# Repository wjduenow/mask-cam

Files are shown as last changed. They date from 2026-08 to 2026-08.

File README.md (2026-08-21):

# mask-cam — a Gini Raksha mask that carries an ESP32-S3-CAM

Converts **Sri_Lankan_Mask_2.3mf** (Tbridge3D, *Sri Lankan Mask (Gini Raksha)*) into a
housing for a nulllab / emakefun **ESP32-S3-CAM**, with the lens looking out of the brow,
a 55 × 55 × 12 mm cell inside, and the electronics sealed behind a screwed cover. It
hangs on a wall or drops onto a printed stand, using the same two mounting points.

| | |
|---|---|
| **Overall** | **193.2 × 74.4 × 187.9 mm** — the donor at **1.75×**, silhouette untouched |
| **Mask** | 323.7 cm³, **~401 g** PLA, watertight, one body |
| **Aperture** | **Ø7.6 at (x 0, z 91)** — the brow, on the mirror line. **79–165°** unvignetted |
| **Battery** | **55 × 55 × 12 mm** cell in a 58 × 58 pocket, 21.2 mm of interior |
| **Parts** | `mask_cam` · `cover` · `stand` · `camera_clamp` · `battery_shim` · `camera_shims` · `eye_plugs` |
| **Power** | [DWEII Type-C boost + charge module](https://www.amazon.com/dp/B09YD5C9QC), 25 × 20 mm — cradled in the board bay, plug enters from below |
| **Nothing protrudes** | past the wall plane except the cover's own hanging pads |

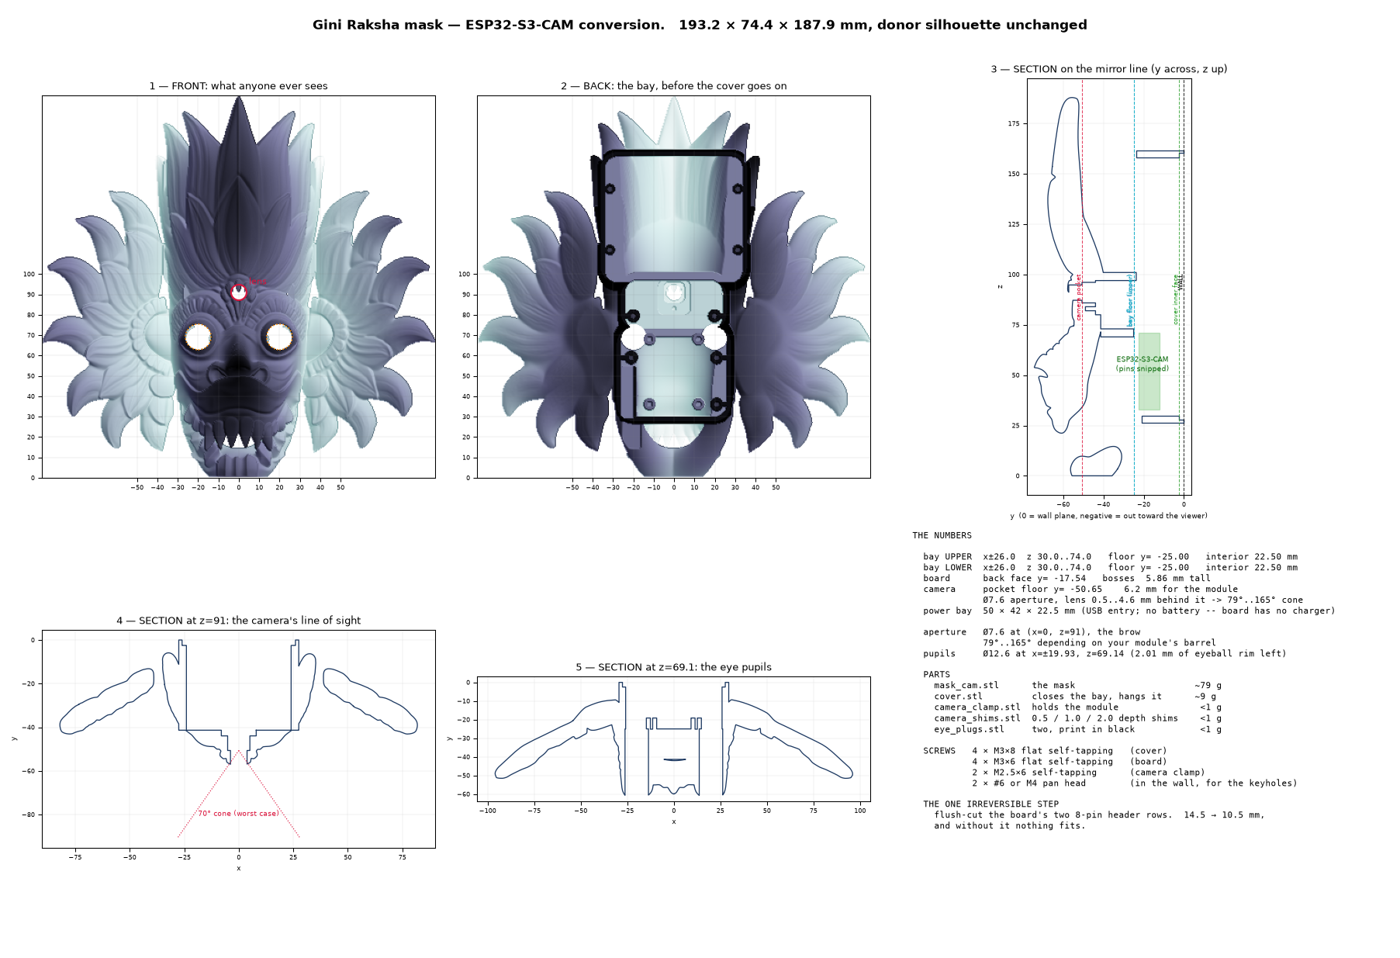
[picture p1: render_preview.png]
preview


---

## 0. You need the donor model — it is not in this repository

Everything here is a **conversion of a third-party model**, and none of it builds without
that model:

> **Sri Lankan Mask (Gini Raksha)** — designer **Tbridge3D** — *Standard Digital File
> License*

That licence covers printing it yourself; it does **not** cover redistribution, so the
file is deliberately absent, along with `mask_cam.3mf` (which carries its geometry
unchanged) and the designer's own product photographs.

Get your own copy, save it beside these scripts as **`Sri_Lankan_Mask_2.3mf`**, then:

```bash
python build_all.py --force      # re-samples the donor and regenerates everything
```

Every derived file — the sampled grids, the mask, the cover, the stand and all the small
parts — is reproduced from it. What lives here is the conversion: the parameters, the
solid modelling, the measurement scripts, and the checkers that refuse to let it lie.

---

## 0.5 Where this stands

Everything in this repository builds and passes its checkers. What is **printed** and what
is **current** are not the same thing:

| | state |
|---|---|
| `mask_cam.stl` | built + verified — **not yet printed** in this form |
| `cover.stl` | built + verified — **not yet printed** in this form |
| `power_clamp.stl` | new — not yet printed |
| `camera_clamp.stl` | **printed, fits** |
| `battery_shim.stl`, `camera_shims.stl`, `eye_plugs.stl` | built + verified |

An earlier mask and cover were printed and are superseded — they predate the cover posts,
the board bosses, the SD-card clearance and the DWEII pocket.

**Power is wired** as far as the cell → module pair; the module's `5V ±` to the cam board
was the step in progress. The boost auto-starts, so nothing needs to come out through the
cover.

Two numbers are still soft, both flagged where they are used: the SD card's span along the
cam board (photo-scaled, `SD_MARGIN` carries 1.0 mm against it) and the DWEII module's
thickness (not dimensioned on its drawing; the pocket is cut oversize so it cannot bite).

One decision is open: the **USB-C port arrangement**. Today the plug enters from under the
chin and needs a slim cable. A cable feed-through with the module somewhere roomier was
raised and never settled.

---

### Resuming with Claude

`CLAUDE.md` holds the operational notes — how to run things, how long each step takes, the
measurement traps that cost time here, and the two rules the project runs on. It loads
automatically. `.claude/skills/parametric-3d-printing/` is bundled so CadQuery work has its
reference to hand.

---

## 1. The idea: carve the bay out of the relief, don't add a box to the back

The donor looks like a thin shell and is not. Ray-sampling it shows **8–27 mm of solid
plastic** (at 1×) over a hollow back, and the relief you actually see is only the outer
few millimetres. So the electronics bay is **milled into that thickness from behind**, and
the apertures are bored through what is left. That is why the silhouette is untouched and
the mask still hangs flat.

### Why 1.75×

The hardware does not scale. That asymmetry is the whole point: at 1× the board, the
camera and a battery were fighting over one short column; at 1.75× each gets its own place.

| | usable column | needed | verdict |
|---|---|---|---|
| 1.0× | 67 mm | 117 mm | ✗ no battery; camera trapped under the board |
| 1.5× | 118 mm | 117 mm | +1 mm — nowhere for cover screws, no home for the charger |
| **1.75×** | **154 mm** | 117 mm | **+37 mm** ✓ |
| 2.0× | 176 mm | 117 mm | +59 mm, but **621 g** |

The column is bounded below by the teeth and above by the crown, which is one continuous
piece only up to **z ≈ 164** — past that it is five separate petals (§5). 2× buys margin
you don't need for another 200 g of filament.

---

## 2. Layout

Three zones, each sized from the measured surface by `analyze_layout15.py`:

| zone | x | z | interior | holds |
|---|---|---|---|---|
| **BOARD** | ±26 | 30 – 74 | **22.50 mm** | the ESP32-S3-CAM (z 32–72) |
| **CAM** | ±24 | 73 – 97 | **35.91 mm** | camera at z 91, DWEII module (25 × 20) behind its clamp |
| **BATT** | ±34 | 96 – 158 | **21.20 mm** | the 55 × 55 × 12 cell |

**The camera is clear of the board** — z 91 against a board ending at z 72. At every
smaller scale the central column was too short and the camera had to live *underneath* the
board, meaning four screws out before you could touch it. It is now serviceable alone.

**The cell has real fixings.** At 1.5× the 58 mm pocket filled its zone edge-to-edge and
the cover's battery section was a 58 mm cantilever held by foam pressure. At 1.75× the
zone is 68 wide against a 58 pocket, so four **Ø5** posts flank the cell — ten cover screws
in total.

---

## 3. Why the brow and not the eyes

You asked for the eyes first, and the eyes are the better-looking site. They are also, by a
factor of five, the **worst optical site on the mask**, and that is measured.

The lens can only get as close to its aperture as the surrounding relief lets the module's
pocket reach. `analyze_fov.py` measured that at every candidate (1× figures):

| site | lens setback | cone at Ø7.2 |
|---|---|---|
| right eye | **11.5 mm** | **35°** |
| left eye | 12.0 mm | 33° |
| mouth | 16.0 mm | 25° |
| nostril | 1.6 mm | 133° |
| **brow** ← | **1.0–5.3 mm** | **71–151°** |

The eyeball is a solid hemisphere boss with thick relief all round it; the brow is a thin
skin over the deep central cavity. A central bore on a Raksha mask reads as an **urna /
third eye** — an authentic motif rather than damage.

### What the lens actually gets

⚠️ **Correcting an earlier claim.** This section used to say the setback was "set to
3.0 mm, giving a 103° cone". `LENS_SETBACK = 3.0` was a stated intent that the geometry
never implemented — the pocket floor is derived from the *relief limit*, not from that
parameter, so the number was dead and the 103° was wrong.

With the module now measured at **6.20 mm** front-of-lens to back (2026-08-18), here is
what it really gets:

| module sits | setback | unvignetted cone |
|---|---|---|
| face flat on the pocket floor, nothing in the bore | 4.59 mm | **79°** |
| barrel nosed the full 4.6 mm up the Ø7.6 bore | 0.50 mm | **165°** |

The geometry assumes the **pessimistic** end: the pocket floor sits at the relief limit
(53.15 mm proud, cut to 50.65, leaving exactly the 2.50 mm wall), and nothing is assumed
to enter the bore. Any real barrel protrusion only moves the lens closer to the aperture,
which widens the view — it can never make it worse.

**79° is the number that matters, and it is comfortably enough.** A stock OV2640 lens is
65–70°, so even at the pessimistic end the aperture never crops the sensor's image. The
glass also sits 4.6 mm down a dark tunnel, so no lens is visible from the front.

> ⚠️ **The sensor is an OV3660, not an OV2640.** Firmware bring-up read the PID off the
> part on 2026-08-20: `0x3660`. The paragraph above was written against the OV2640's
> figures. OV3660 modules ship with comparable glass, so the conclusion very probably
> survives — but the 65–70° it leans on is now an assumption about a part we have not
> measured, and only a photograph through the finished aperture will settle it. The
> aperture is oversized against 79° anyway, which is the margin that makes this a footnote
> rather than a problem. See `firmware/README.md`.

Both eyeballs get **Ø12.6** bores and printed blanking plugs — the symmetry is what makes
the brow bore read as ornament. The aperture itself is **not** scaled: it only has to pass
the real Ø7.0 lens, so on the bigger mask it is proportionally smaller and harder to spot.

---

## 4. Where every number came from

The honest ledger. ⚠ rows are the ones that move plastic.

### Measured off the donor mesh (0.5 mm ray grid, re-run on every build)

| what | value | how |
|---|---|---|
| bounding box | 193.2 × 74.4 × 187.9 | trimesh, watertight |
| **eyeball centres** | **x = ±19.9, z = 69.1** | peak stand-off in the eye band, centroid-fitted |
| crown continuity | one piece to **z ≈ 164** | connected-component scan per z row |
| BOARD zone | 39.60 mm worst stand-off | rectangle minimum over x±26, z 30–74 |
| CAM zone | 41.41 mm | over x±24, z 73–97 |
| BATT zone | 26.70 mm | over x±34, z 96–158 |

> **The eyeball detection is self-checking.** The two caps come out symmetric to **0.14 mm
> in x and 0.00 mm in z**. A detector locking onto noise does not do that — an earlier
> version whose search band was left in *unscaled* coordinates landed on the **nostrils**
> and returned 3.5 mm caps instead of 7 mm. If you change `MASK_SCALE`, check that
> agreement before trusting the result.

### From the vendor's KiCad STEP (via `../sonos-nest/hardware/cam-button`)

| what | value |
|---|---|
| PCB | 30.4 × 38.4 × 1.60 (40.0 overall with the USB-C shell) |
| mounting holes | Ø3.20 on 24 × 32, Ø6.40 keep-out — **M3, not M2**. ✅ Confirmed by a 40.00 mm measured diagonal |
| tallest top-side part | 4.96 (USB-C shell) from the PCB **back** face |

### Measured on the board in hand (V1.1, 2026-08-18)

| what | value | consequence |
|---|---|---|
| header rows | **bare plated holes** | nothing to snip — the old "flush-cut the pins" step is void |
| J1 / J2 | **unpopulated footprints** | the back face is flat |
| total thickness | **7.50 mm** with power wires on | `REAR_PROTRUSION` = 2.54 |
| **camera module** | **6.20 mm** lens front → back | supersedes the 5.0 + 2.0 estimate; pocket offers 6.70 |
| VBAT with USB connected | **0 V** | **there is no charger on this board** (§7) |

### Derived, never typed

```
FLOOR_Y_*    = -(min stand-off over the zone - FRONT_WALL)
BOARD_SEAT_Y = FLOOR_Y_UP + BOARD_FRONT_CLR + COMP_Z_MAX - PCB_T
CAM_SEAT_Y   = CAM_POCKET_Y + CAM_MODULE_DEPTH + 0.5
```

Change `MASK_SCALE`, `FRONT_WALL` or a zone outline and everything downstream moves with
it. There is no second number to forget.

---

## 5. The checks, and what they caught

`build_mask.py` runs **55 clearance checks before it will build**; `verify.py` re-measures
the **exported STL** afterwards with **16 more**. Between them they caught six real
defects:

- **The bay floors.** A hand-made sampling table said they were fine; the true rectangle
  minima would have broken through the relief by 0.68 mm.
- **Every boss and post was floating.** The bay floor is a *plane* at the zone's worst
  case; the donor's back is a *dish*, already deeper than that plane almost everywhere, so
  pillars based on it stood in 2.5–7.6 mm of nothing. Each is now rooted on its own local
  rear surface.
- **Board bosses were 1.6 mm too tall** — they topped out at the PCB's *back* face when the
  board seats on its *front*, inside the Ø6.4 keep-out ring. Exactly `PCB_T` of error.
- **The battery zone severed the crown.** Reaching past z ≈ 164 put its top wall across
  five separate petals, and because the wall sits behind their rear surfaces it never
  merged — the mesh came apart into four bodies. Petals are not structural ground.
- **The USB-C port cut sat at floor depth** instead of on the receptacle's midline, eating
  forward into the muzzle and leaving 1.28 mm of relief.
- **The module was captured, not fastened.** Its pocket had a lid across the mouth and
  the cover closed the far end, so there was no way to screw it down and the soldered
  wires had to be dressed while feeding a board into a blind slot. The pocket is open to
  the bay now, with an **undercut lip** at the bottom — which is why the cradle is built
  as its own boolean assembly in `build_pillars()` rather than as one cutter: a lip that
  overhangs the mouth *without* making the pocket shallower cannot be cut in one pass.
- **The cam board is 38 mm wide, not 30.4.** With a microSD card seated, the slot region
  juts **7.6 mm past one long edge**, and nothing in `mask_params.py` knew — the whole bay
  was laid out around a bare PCB. Measured off the board's own 32 × 24 mm hole pattern in
  an assembly photo, the card occupies **z 51.7–66.0** and reaches **x = −22.80**, which
  put it straight through the DWEII cradle (4.3 mm of overlap) and through the cover post
  at (−21, 59). The card cannot move — it is where the board's slot puts it — so the
  cradle moved to the **+x** wall and the board-zone posts were re-cut around both. ⚠ The
  z band is photo-scaled; `SD_MARGIN` carries 1.0 mm against it.
- **A mount was cut for a part that is not in this build.** `mask_params.py` carried a
  `UC_*` block for a SparkFun-pattern USB-C breakout — 21.4 × 14.5 × 4.75, two M3 holes
  16.85 apart — copied from `../sonos-nest/hardware/jukebox-7`. README §7 had *already*
  replaced that part with the DWEII module, and the part in hand was always the DWEII
  ([B09YD5C9QC](https://www.amazon.com/dp/B09YD5C9QC), drawing in `dweii_spec.jpg`). A
  pad, two pilots and a port channel were cut for a board nobody owns, and the board-zone
  post layout was re-cut around it. Its numbers could not have worked either: the slab
  outboard of that pad is **4.87 mm**, not the nominal wall, so its 6 mm pilots came out
  through the cheek. The whole block is gone; the mount now derives from `PWR_*`, and the
  module is cradled rather than screwed because it **has no mounting holes**.
- **Every cover post and every board boss was built, then deleted.** `build_mask.py`
  unioned the pillars into the mask and *then* carved the bay, and the zone cutters span
  each zone's whole footprint from its floor back to the wall plane — so all 14 pillars
  were erased by the bay they stood in. The exported mask had cover screw holes with
  nothing behind them and a board with nothing to sit on, for months, and `verify.py`
  reported "all checks passed" because it never looked. Walls are added before the carve
  now and pillars after it; §4b of `verify.py` probes the mesh for all 14 and their
  pilots.
- **Two collisions the deleted posts had been hiding.** With the pillars restored, the
  posts at (±21, 68) turned out to sit **1.56 mm** off the eye-pupil axis — inside a
  Ø12.6 bore that needs 9.55 mm of clearance — and capped both pupils; and the post at
  (−21, 36) went straight through the USB-C breakout, leaving gaps of 1.75 and 2.55 mm
  for a board 4.75 mm thick. The board-zone layout was re-cut around all three claimants
  (pupils, breakout, cam board), and `check_clearances()` now asserts each one.
- **The USB-C breakout mount was specified but never built.** `mask_params.py` had the
  pad, the pilots, the port and the receptacle offsets; `build_mask.py` referenced none
  of them. It also could not have worked as written: the slab outboard of the pad is
  **4.87 mm**, not the nominal wall, so the 6 mm pilots would have come out through the
  cheek — the mask's silhouette runs out before its wall does.
- **Three measurement bugs found while fixing those.** A pupil diameter measured by
  line-of-sight through the whole mask reported 11.0 mm for a 12.6 bore, because a boss
  legitimately stands behind it — it now measures the bore itself. A relief sample cast
  exactly along the USB-C pad's face grazed it, returned an odd number of crossings, and
  reported 0.00 mm of relief where there is 19; the sample grid is nudged off round
  numbers now. And a cutter left flush with that same face made a coplanar pair in the
  boolean.
- **The camera clamp was cut to a seat that does not exist.** `CAM_SEAT_Z1` asks for
  z = 102, but the battery zone's floor crosses the waist at z = 97 and sits 20 mm
  *behind* the seat, so the last 5 mm of it is a sealed void inside solid plastic — and
  the second clamp pilot went into that void. The clamp came out 21.5 mm long for a
  17.0 mm recess and had one of its two screw holes over nothing. Every dimensional check
  passed: they all asked the *parameters* whether the seat was 22 mm long, and none asked
  the *mesh*. `verify_smalls.py` now places both small parts in the mask mesh and fails on
  any overlap, and `build_mask.py` asserts that no seat outruns its own zone and no pilot
  lands where a screwdriver cannot reach.
- **The keyholes were inverted** — entry circle above, capturing slot below. Every
  dimensional check passed, because none of them asked which way up it was; the mask would
  simply have slid off the screws. `verify_cover.py` now asserts the entry sits *below* the
  resting position, and probes the mesh for solid material above the shank.
- **Extending the bay downward filled a tooth gap.** A wider lower bay put its wall through
  the mask's teeth; `verify.py` caught it closing one. Face area in the muzzle is paid for
  out of the mouth.

It also caught **three bugs in itself**, worth recording because a checker that measures
the wrong thing is worse than none:

- `cast()` returns crossings **rear-first**, but the relief check took `ys[0] - ys[1]` —
  the *rearmost* solid span. At the failing point the spans were 1.28 / 14.32 / **8.12**
  and the relief was the 8.12. It now sums solid material **forward of the bay floor**,
  ignoring sub-0.15 mm tessellation slivers (reported, not hidden).
- Volume bounds, sample points and the eye search band were all hardcoded at 1×.
- A 1e-6 mm tolerance flagged manifold's own floating-point noise as a geometry change.

Current result on the exported mesh:

```
relief in front of the bay >= FRONT_WALL   thinnest 8.40 mm  (design min 3.00)
camera pocket relief >= CAM_WALL           thinnest 2.46 mm  (design min 2.50)
board envelope unobstructed                0 obstructed samples
front surface identical off-bay            7 scaled sample points
bounding box == donor's                    [193.24, 74.35, 187.91]
```

---

## 6. Parts

| file | size | mass | notes |
|---|---|---|---|
| `mask_cam.stl` | 193.2 × 74.4 × 187.9 | ~401 g | the long print |
| `cover.stl` | 71.5 × 130.3 × 7.5 | ~26 g | 3 walls, 25 % infill; **vented** (§7) |
| `stand.stl` | 181.6 × 99.7 × 137.4 | ~151 g | optional, for a mantel |
| `camera_clamp.stl` | 15.6 × 16.6 × 3.2 | ~1 g | **one** M2.5, cut to the seat that is really in the mask — see §6.1 |
| `battery_shim.stl` | 62 × 56 × 13.2 | ~10 g | fills the 9.20 mm between the cell and the cover, and locates the cell |
| `power_clamp.stl` | 16.0 × 10.5 × 3.5 | <1 g | one M3 holds the DWEII module in its pocket — fastened, not trapped |
| `camera_shims.stl` | 3 shims, 0.5 / 1.0 / 2.0 | <1 g | take up the 0.50 mm of slack behind the module |
| `eye_plugs.stl` | 2 plugs, Ø12.45 | ~2 g | print in black |

---

## 7. Power — and why the cell needs the DWEII module

**Measured, not assumed: the cam board has no charger.** With USB connected and no cell
fitted, the VBAT pad reads **0 V** — nothing drives it. The 0 V is also good news about the
power MUX: had the P-FET been reversed, its body diode would have put ~4.1 V there and
pushed uncontrolled current into any cell. It doesn't.

So charging happens on a **DWEII Type-C boost + charge + protect module** — **25 × 20 mm**,
5 V 2 A out, 2.4 A charge, and it **charges and discharges simultaneously**, which is what
makes it a UPS rather than a swap-the-cell arrangement. One board replaces a passive
breakout *and* a separate charger:

```
USB-C cable ──► DWEII  Type-C socket        (charges the cell)
                       + / −  pads  ──► cell
                       5V     pads  ──► cam board J4 pin 1 (`5V`) + pin 2 (`GND`)
```

Nothing depends on the cam board's own power path.

### The module's pads — READ OFF THE SILKSCREEN

```
        ┌─── K ───┐   K   switch input (开关).  A momentary button to `−`.
        │  +   −  │   +/− BATTERY pair
        │         │
   5V + │         │   5V+ / 5V−  OUTPUT pair, to the cam board
   5V − │ [USB-C] │
        └─────────┘   IC: HOTCHIP PB005 3A.  Four LEDs, lower right.
```

⚠️ **The button gates the output and the gauge together** — they are not separable on this
IC, and while a charger is plugged in the gauge lights regardless of it. A button gets you
"camera off, LEDs off" or "camera on, LEDs on". To kill the LEDs alone, desolder the four
of them; charging, boost and protection are untouched by that.

The bay is not lit by them anyway: the module fits **components toward the wall**, which
puts the LEDs ~0.5 mm off the solid back of their pocket, and the eye plugs blank the only
20 mm sightlines out of that bay.

✅ **The boost auto-starts — TESTED 2026-08-20, no button press needed.** So `K` is left
unwired, nothing has to be brought out through the cover, and the mask comes back up on
its own after a power cycle. This was the one open question that could have forced a
redesign of the cover, and it did not.

⚠️ The corollary: modules that wake on load current also **sleep on the absence of it**,
typically somewhere around 50–70 mA. Streaming MJPEG the S3 is nowhere near that, so it
does not bite here — but firmware that ever puts the board into deep sleep could drop
below the threshold, and the module would then shut off and need a press to come back,
from inside a sealed mask. Keep the board awake, or bleed enough current to stay above the
cutoff.

### ⚠️ Cell polarity — and why the LEDs will not tell you

The module carries **four LEDs, a 25 %-per-segment fuel gauge**. The top segment pulses
while charging and goes steady when it is done.

**A reversed cell shows all four segments lit, exactly like a full one.** With the battery
pair backwards the module reads its own open-circuit charger output and reports "full" —
which is the same picture as a cell that is genuinely charged, so the gauge cannot be used
to confirm the wiring. This happened during assembly on 2026-08-20.

Two facts make it easy to catch before it matters:

- **A new pouch is never full.** LiPos ship at storage charge, ~3.7–3.8 V, which is one or
  two segments. Four segments on a cell you have not charged yet means the wiring, not the
  charge.
- **Meter it at the cell's own leads, not by wire colour.** Red/black is a convention, not
  a guarantee.

Bench-test the module **before** it goes in the pocket — once it is behind the clamp its
pads face the wall and a probe will not reach them:

| check | expected |
|---|---|
| cell voltage, at the cell's leads | 3.7 – 4.2 V |
| `5V` pads, USB plugged in | ~5 V |
| `5V` pads, USB **unplugged** | ~5 V — proves the cell is live in both directions |

The third is the one that proves the battery pair, because it only works off the cell.

**If a cell has been connected backwards**, the charge path may survive — it did here — but
the protection circuit is what fails silently, and a module that charges and boosts
normally can have a dead over-discharge cutoff. Watch the first full charge for heat, check
the cell still reads ~4.1–4.2 V the next morning, and check the pouch for swelling. The
modules come ten to a pack; spend a fresh one rather than trust a suspect one.

It lives in the **CAM waist**, which has
38 mm of interior and only ~10 of it used by the camera clamp.

### Finding the pads — and WHICH of the two 5V pads to use

CONFIRMED against the board in hand (silkscreen **SP32S3 CAM V1.1**), 2026-08-20. It is a
**column** down the back's left edge, not a row. Count from the corner mounting hole — the
`5V` pad is the **first**, and the only one on the strip with a **square** outline rather
than a circle. If the pad you are about to solder is round, it is the wrong pad.

```
   left edge, plated through-holes        middle, four flat SMD pads
   ────────────────────────────────       ──────────────────────────
   ○  mounting hole  (the corner)           GND   5V   47   48
   ▣  5V   1st pad, SQUARE   ✅ live               ↑
   ○  GND  2nd pad           ✅ ground             same net, DO NOT USE
   ○  1    3rd pad  ⛔ GPIO1 — NOT THIS ONE
   ○  48
   ○  NC
   ○  47
   ○  14
   ○  0
```

⚠️ **"Square pad" and "the pad marked `1`" are different pads, and confusing them is the
way this board gets killed.** A square outline is the PCB convention for the first pin of
a connector — it is about the pad's SHAPE. The pad silkscreened `1` is GPIO1 — it is about
the LABEL, and it is the third one down. This file used to say "the square pad is `5V`,
pin 1", which collided the two ideas in one sentence and very nearly cost an S3.

**Both `5V` pads are the same rail. Solder to the EDGE pair.** The reason is what each one
sits beside:

| | `5V`'s neighbours | a solder bridge gives you |
|---|---|---|
| edge column | end of row, and `GND` | 5 V shorted to GND — the supply current-limits, nothing dies |
| middle row | `GND` one side, **`47`** the other | **5 V into GPIO47 — dead S3** |

The middle pads are small, close together and flanked by GPIOs; the edge pads are plated
through-holes whose only live neighbour is ground, so the worst case is a short you notice
rather than a part you have destroyed. Through-holes also take wire strain, where a flat
SMD pad lifts.

⚠️ The pad marked **`1` is GPIO1, not a power pin** — a signal pin on a 3.3 V part, and
5 V into it kills the S3. It sits two below `5V` on the same column.

---

### Cooling

The bay is otherwise sealed and MJPEG streaming runs the S3 hard, so the cover carries
**nine 26 × 2.6 mm vent slots — 595 mm², 6.4 % of its plan area.** They face the wall, so
they cost nothing visually; this is the one surface where venting is free.

They are placed as a **chimney, not as decoration**: an intake bank below the board
(z 33–39) and an exhaust bank above it (z 65.5–72.5), 57 mm apart, so convection has
somewhere to go once the mask hangs vertically. A third bank over the waist (z 82–90)
serves the DWEII boost converter, which dissipates at 2 A.

**Nothing is vented over the cell.** Warm air drawn across a LiPo is the opposite of what
you want, and heat is what ages a pouch fastest. `verify_cover.py` asserts the cell band
(z 98–156) stays solid, that every slot clears all ten countersinks and both hanging pads,
and that the slots stay inside the x = ±21 post columns so the plate's load paths are
untouched.

> ⚠️ **Vents leak light both ways.** The board's power LED and its GPIO3 flashlight LEDs
> will be faintly visible around the mask's edge in a dark room. If that matters, mask
> them off or drive GPIO3 low.

---

## 8. Assembly

**Order matters** — the camera and the cell go in before the board is bolted down.

1. **Solder two wires to the cam board** while it is out and both faces are reachable. Feed
   them from the **back** so they exit toward the cover; the space in front of the board is
   the ribbon plenum.
2. **Camera module** into the pocket at (0, 91), lens forward into the Ø7.6 bore. Push it
   as far forward as it will go — every millimetre the barrel enters the bore widens the
   view (§3).
3. **`camera_clamp.stl`** over it, **one** M2.5 × 6 into the pilot at z = 83 — the only one
   there is (§6.1). Feed the ribbon **up through the slot in the clamp itself** — it runs
   on the mirror line from below the pocket's lower lip to the top of the pressure rib —
   and lay it over the clamp *before* you fit the screw. The clamp's top face finishes
   flush with the waist floor and every edge the ribbon crosses is chamfered, so nothing
   is pinched and nothing is creased. The pocket offers
   **6.70 mm** against the module's measured **6.20**; the clamp's U-rib takes up 0.65 of
   that, and a 0.5 mm shim behind the module takes up the rest if yours sits low.
4. **Fold the excess ribbon** into the plenum. The module ships on a **75 mm** FPC against a
   much shorter path, and it cannot be trimmed — the gold fingers are the termination.
   S-fold it; don't crease it.
5. **DWEII module** into its pocket on the board bay's **−x** wall, **components facing
   the wall** so the clamp bears on a flat PCB back. Tuck its lower edge under the fixed
   lip, swing the top in, then **`power_clamp.stl`, 1 × M3 × 6** into the pilot at z = 57.
   The pocket is open to the bay, so the module is fastened before the cover goes near it
   and the soldered wires can be dressed with everything in view. The board has no
   mounting holes of its own — the clamp is what replaces them.

   The plug reaches its socket up a **channel through the back of the chin**, which
   leaves 4.6 mm of relief at its thinnest and is invisible from the front. ⚠ Use a
   **slim** USB-C cable: the channel is 9 mm across and a chunky moulded plug will not
   go up it.

   Wire its `5V` output pads to J4 `5V`/`GND`, and its `+`/`−` pads to the cell.
6. **Cell** into the battery zone, then **`battery_shim.stl`** on top of it, ribs facing the
   cell's back and the two tall walls straddling it. It fills the 9.20 mm that would
   otherwise let the cell move, and holds it in x, which is the axis with 4.7 mm of slop.
   Feed the tabs out through either wire gate. **Do not glue the cell** — LiPo pouches
   swell with age and a glued-in cell is a dead mask, which is the whole reason the shim
   is a separate printed part rather than a blob of epoxy.
7. **Board** onto the four bosses, component side **facing forward**, USB-C pointing
   **down**, 4 × M3 × 6 flat self-tapping. ⚠ **That orientation is what decides which
   side the SD card sticks out** — component side forward puts it at −x, which is why the
   DWEII cradle lives on the +x wall. Mount the board the other way up and the card
   collides with the cradle.
8. **Eye plugs**, pushed in from the front with tweezers.
9. **Cover**, 10 × M3 × 8 flat self-tapping. Countersinks face the wall and must sit flush;
   a proud head rocks the mask.
10. **Hang it** — two #6 or M4 pan-head screws **38.5 mm apart**, or drop it on the stand.
    The keyholes take the head through the **lower, round** end and capture the shank at
    the **upper, narrow** end: offer the mask up, engage both heads, then let it drop 5 mm.

### Screws

| where | qty | screw |
|---|---|---|
| cover → posts | 9 | M3 × 8 flat, self-tapping |

| board → bosses | 4 | M3 × 6 flat, self-tapping |
| camera clamp | 1 | M2.5 × 6 self-tapping |
| power clamp → its pilot | 1 | M3 × 6 flat, self-tapping |
| wall (or the stand's pegs) | 2 | #6 or M4 pan head |

All thread-forming into bare printed plastic — no nuts, no heat-set inserts.

---

## 9. The stand

`stand.stl` carries two mushroom pegs on the **mask's own keyhole spacing**, so the mask
drops onto it exactly as onto wall screws. One interface, two uses, and no change to the
mask.

**18° lean, from measurement.** The mask's centre of mass sits **34.2 mm forward** of its
back plane and 84.4 mm up, so upright it tips forward. Leaning back moves that overhang
toward the pivot — `34.2·cos θ − 84.4·sin θ` — reaching zero at ~22°. At 18° the mask
overhangs by 6.49 mm, killed by a base reaching 60 mm forward. Mask and stand together put
the combined CoM **7.24 mm** forward with **52.8 mm** of base ahead of it.

A **14 × 8 mm cable channel** runs out the back of the base, with a notch through the panel
foot so the cable can turn into it — sized for a USB-C overmold, not the bare cable.

| assembled | |
|---|---|
| on the stand | 193 W × 100 D mm — needs **100 mm of shelf depth** |
| on a wall | 193 × 188 mm, standing 5.0 mm proud |

---

## 10. Print

| part | orientation | supports |
|---|---|---|
| **mask_cam** | upright, as the donor's own plate has it | yes — as the donor already needs |
| **cover** | **inner face down** | none |
| **stand** | **flat on its back panel** | none |
| **camera_clamp** | **top face down** — as exported | none |
| **battery_shim** | **face plate down** — as exported | none |
| **shims / plugs** | flat | none |

- The mask keeps the designer's orientation because that is what the relief was drawn for.
  Everything added runs **parallel to Y**, horizontal in that orientation, so the bay walls,
  floors and every bore are vertical-walled features rather than bridges.
- **Cover inner face down** puts the wall-facing side — the one that must stay flat — on the
  bed, and opens the countersinks and the keyhole undercut upward.
- **Stand flat on its back panel** faces every overhang up.
- **Clamp top face down** makes the countersink a self-supporting cone and leaves the
  pressure rib as the last thing laid down. **Shim face plate down** puts the face that
  meets the cover on the bed and stands every rib up off it. Both are exported already
  rotated — drop them on the plate and do not re-orient them.
- PLA or PETG, 0.2 mm layers. The donor's profile (2 walls, 5 % infill) suits the mask. Give
  the **cover 3 walls / 25 % infill** — it carries the mask's weight through its screws —
  and the **stand 3 walls / 25 %**, since it carries the whole 403 g.
- Print the mask **dark** if you can. The apertures read as shadow; a Ø7.6 hole in pale
  filament is a Ø7.6 hole.

Everything is verified before the print starts — `build_all.py` refuses to write an STL
that fails a check.

---

## 11. Still open

1. ~~The DWEII module.~~ ✅ **Verified from the manufacturer's dimension drawing: 25 × 20 mm**
   (3 mm wider and 2 mm shorter than the guess it replaced — the waist grew from 22 to
   24 mm in z to suit). Thickness is not dimensioned there; ~5.5 mm is carried, and with
   35 mm of waist interior it cannot plausibly bind. Caliper it only if you want the exact
   number. Note it has **no USB-A socket** — the output is solder pads marked `5V`.
2. ~~The camera's barrel length.~~ ✅ **Measured: 6.20 mm** front of lens to back. What is
   still unknown is how that splits between protruding barrel and holder body, which is
   the difference between a 79° and a 165° cone. It does not gate the print — the geometry
   assumes the pessimistic split and 79° already exceeds the sensor's own field.
3. ~~The cam board's hole pitch.~~ ✅ **Settled: the diagonal is 40.0 mm**, which is the CAD
   pattern (24 × 32) to two decimal places and rules out the 23 × 31.75 reading by 0.79 mm.
   The bosses stay at (±12, 52±16). A single diagonal measurement was worth more than three
   separate pitch readings, because the two candidates differ by 0.79 mm on it while each
   individual pitch reading was within caliper slop.
4. **Your keyhole screws.** Ø7.5 head / Ø4.2 shank suits a #6 or M4 pan head. Leave them
   standing ~4 mm proud of the wall — the pads are 5 mm thick and the head must sit in the
   cavity behind the capturing lip.

**Nothing else gates the print.** Every dimension that could move plastic has now been
either measured on the hardware or verified against a manufacturer drawing:

| was uncertain | resolved | how |
|---|---|---|
| header pins add 4 mm | **no pins fitted** | the board in hand |
| board has a charger | **it does not** — VBAT reads 0 V | multimeter |
| camera module depth | **6.20 mm** | calipers |
| which sensor | **OV3660**, not OV2640 | PID `0x3660` read off the part |
| DWEII module size | **25 × 20 mm** | manufacturer's dimension drawing |
| board hole pattern | **24 × 32** | 40.00 mm diagonal |

---

## 12. Files

```
mask-cam/
    README.md              <- you are here
    mask_frame.py          the donor loader, MASK_SCALE, and the canonical frame
    mask_params.py         every dimension; floors and seats are DERIVED at import
    measure.py             queries against the sampled surface -- one source of truth
    geom.py                solid-modelling helpers (trimesh/manifold)

    build_all.py           everything, in order, then verifies
    build_mask.py          mask_cam.stl  + 55 clearance checks
    build_cover.py         cover.stl                       (CadQuery)
    build_stand.py         stand.stl                       (CadQuery)
    build_smalls.py        camera_clamp / power_clamp /
                           battery_shim / shims / plugs    (CadQuery)
    verify.py              re-measures the FINISHED mask   (16 checks)
    verify_stand.py        pegs vs keyholes, and tipping
    verify_smalls.py       puts the clamp and the shim IN the mask mesh and asks
                           whether they overlap it -- the check that would have
                           caught the seat (see below)
    render_preview.py      render_preview.png
    render_smalls.py       smalls.png -- both small parts, in place
    render_bay.py          bay.png -- every post, boss and the USB-C mount, which is
                           the picture that would have shown they were missing

    analyze_*.py           the provenance: how the donor was measured, why the brow won,
                           and how the 1.75x layout was chosen.  Kept because this
                           README's tables are only as good as the scripts behind them.
```

Two toolchains on purpose: the mask is a **1 M-face mesh**, which no B-rep kernel will
ingest, so it is **trimesh + manifold3d** (a full boolean takes ~1 s). The free-standing
parts are clean parametric solids with countersinks and undercuts, so they are **CadQuery**.

```bash
python build_all.py          # -> all six STLs + preview, verified
python build_all.py --force  # re-sample the donor (needed after changing MASK_SCALE)
```

Requires `cadquery, trimesh, manifold3d, shapely, scipy, matplotlib, mapbox_earcut, rtree`.

**To change scale:** set `MASK_SCALE` in `mask_frame.py`, then `build_all.py --force`. The
donor-derived constants follow it; the electronics do not. Afterwards, re-check the eye
detection's symmetry and that the battery zone still clears the crown petals — those are
the two things that silently break.

---

## 13. A note on use

A camera concealed in décor is unremarkable in your own home. Recording other people
without their knowledge is regulated in most US states, and **audio** more strictly than
video — several states require all-party consent. Worth knowing before it points at a room
other people use.

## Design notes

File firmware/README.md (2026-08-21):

# firmware — the software half of mask-cam

The board is a **nulllab / emakefun ESP32-S3-CAM**, silkscreen `SP32S3 CAM V1.1`.
Everything here follows the same rule the CAD side runs on: **verify against the hardware,
not the datasheet.** What is written down was read off the part in hand.

Two environments:

| | what it is | when |
|---|---|---|
| **`mask-cam`** | the real thing — live MJPEG, AVI clips to microSD, web UI | default |
| **`selftest`** | four questions the board answers about itself, in 20 s | when in doubt |

---

## Confirmed against this board, 2026-08-20

| | | how |
|---|---|---|
| chip | ESP32-S3, rev v0.2, 2 cores @ 240 MHz | `esptool flash_id` |
| flash | **8 MB**, eFuse says **quad** | `esptool flash_id` |
| PSRAM | **8 MB octal** | `ESP.getPsramSize()` |
| sensor | **OV3660** — PID `0x3660` | `esp_camera_sensor_get()` |
| microSD | 32 GB SDHC, mounts **1-bit**, write round-trips | selftest |
| USB | the S3's **own** USB (`303a:1001`), no bridge chip | `lsusb` |
| SVGA frame | 21–69 kB, mean **25 kB** at quality 12 | 454-frame clip |
| sustained | **10.0 fps at 800×600 while recording**, <1 % dropped | 44 s + 10 min runs |
| clip size | ~8–16 MB per 60 s clip at SVGA/10 fps | the card |
| WiFi join | 4 of 4 boots, ~3 s each, with the camera already running | reboot trials |
| SD write | typically 40 ms, **worst 299 ms** | see "the queue" below |
| card life | ~0.27 MB/s at SVGA/10 fps → **~30 h** on 32 GB | measured |
| WiFi | joins, **−76 dBm** from the bench to the AP | `/health` |
| clock | NTP answers; clips name themselves `20260821-055559.avi` | the card |

The pin map is in `src/board_pins.h`, from the vendor's own repo,
[nulllaborg/esp32s3-cam](https://github.com/nulllaborg/esp32s3-cam). Two independent things
corroborate it: the flash and PSRAM sizes it claims match what the part reports, and the
GPIO3 flashlight it names is the LED the main README's cover section already warned leaks
out through the vent slots.

## Setting it up

```bash
cp src/secrets.h.example src/secrets.h     # then put your WiFi in it
$EDITOR src/secrets.h                      # gitignored; it never leaves this machine

~/.platformio/penv/bin/pio run -t upload             # the application
~/.platformio/penv/bin/pio run -e selftest -t upload # the bring-up checks
```

Then `http://mask-cam.local/` — live view, a record button, the clip list, and a health
readout. The stream is on port **81**; the page knows this.

**It records on its own.** The board arms itself as soon as the card mounts — before the
network, so the first frame is on the card seconds after power rather than twenty seconds
later — and keeps a **rolling window** by deleting the oldest clip when the card runs low.
Roughly **30 hours** at SVGA/10 fps. Nothing has to be pressed, and a power cut cannot
leave it streaming happily and recording nothing. Both behaviours are `#define`s in
`config.h` (`MC_RECORD_ON_BOOT`, `MC_DEFAULT_RING`), and the ring has a checkbox in the UI.

⚠️ **Ring mode destroys the oldest footage by design.** That is the point of it, but it is
worth saying out loud: anything you want to keep has to come off the card.

All of it was exercised against the board on 2026-08-21: the page, `/still` (800×600 JPEG),
`/stream` (multipart, 27 frames in 10 s), `/rec` on and off, `/files`, `/download` and
`/delete`, plus the path-traversal guards on the last two. A clip pulled over HTTP and the
same clip pulled over USB came back **byte-identical**, and ffprobe opens both.

`pio device monitor` needs a real terminal and dies without one, so:

```bash
~/.platformio/penv/bin/python tools/board.py log 25          # reset, print output
~/.platformio/penv/bin/python tools/board.py frame out.jpg   # grab a picture, LOOK at it
```

## Talking to it over USB

The board finishes up behind a screwed-down cover, and the day WiFi is the thing that broke
is the day you need another way in. Everything the web UI does, the USB console does:

| | |
|---|---|
| `s` | status — fps, clip, card, queue, temperature, link |
| `r` | start / stop recording |
| `l` | list the clips on the card |
| `d` | dump the newest clip as base64, to be decoded at the other end |
| `m` | recent motion events |
| `?` | this list |

## How it fits together

```
  OV3660 ──► capture pump (core 1) ──┬──► published frame ──► /stream, /still
                 10 fps              │
                                     └──► 4-slot PSRAM queue ──► writer (core 0) ──► AVI
```

Three decisions worth knowing:

**One pump, not two consumers.** The stream and the recorder both want frames from one
sensor. If each called `esp_camera_fb_get()` they would halve each other's rate and starve
each other unpredictably. A single task grabs at the target rate and publishes; everything
else reads the publication.

**The card gets its own task.** This was measured, not guessed. With the SD write on the
capture path, a 240 ms write spike showed up as a stutter in the live view and pulled the
sensor from 10.0 fps down to 7.7. Moving it behind a four-slot queue holds a steady 10.0.
When the queue fills, frames are **dropped and counted** rather than silently stretching
the frame interval — a recording that quietly runs slow is worse than one that admits it
lost four frames. `dropped` is on the health page for exactly this reason.

**Clips, not one long file, and each one kept real on the card.** AVI stores sizes it
cannot know until the file is finished, so the header goes down as zeroes and is patched
at close. Patched *only* at close, an interrupted clip is not truncated — it is **zero
bytes**, because nothing reaches the directory entry until then. Measured, not assumed:
two 0-byte files turned up on the card after resets, and the README used to claim a power
cut cost you the tail of a clip when it actually cost the whole minute.

So the header is patched and the file synced every **5 s** while recording. A clip cut
short by a power failure now plays up to the last sync: a simulated cut left a 7.4 MB file
that ffprobe reads as 506 frames / 50.6 s and ffmpeg decodes without a single error.
`AVIF_HASINDEX` is deliberately set only at close, so an interrupted clip never advertises
an index that was never written. Anything still smaller than a header is swept at boot —
an always-on camera behind a screwed-down cover would otherwise collect one dead file per
power blip forever.

**Every clip carries a sequence number.** `000700001_20260821-143808.avi` is boot 7, clip 1.
Ring mode has to answer "which is oldest" at all times, including the seconds after boot
when there is no clock yet, and neither obvious answer survives that — see the note in
`recorder.cpp`. One NVS write per boot, not per clip.

## Which way is up

The module goes into the mask's pocket lens-forward, which puts the sensor in upside down —
the bench image came out inverted, scene and all. Both defaults are therefore **on**:

```c
#define MC_DEFAULT_VFLIP      1
#define MC_DEFAULT_HMIRROR    1
```

**A 180° rotation needs both axes.** Setting only `vflip` turns the picture the right way
up and leaves it **mirrored** — which nobody notices until they try to read something in
the footage. The way to tell the two apart without any text in frame is to watch what
crosses the frame: under a real 180° rotation, something on the left must end up on the
right. Verified that way here.

Live values live in **NVS**, not just in the build, so whatever you settle on survives a
power cut and every OTA. Two checkboxes in the UI (`flip ↕` / `mirror ↔`), or
`/config?vflip=1&hmirror=1`, and `/health` reports both.

## Updating it over the air — and why that is not optional

⚠️ **Once the cover is on there is no wired path to this chip.** The USB-C that reaches
the outside goes to the **power module's** charging socket; the ESP32's own USB is on the
cam board, inside the sealed bay, behind ten screws. The USB console described above stops
being reachable the moment the mask is assembled. OTA is the only way firmware ever
changes after that.

The flash was already laid out for it — `default_8MB.csv` gives two 3.3 MB app slots and
an `otadata` block, and the image is under 1 MB.

**Two routes, one mechanism.**

```bash
# 1. espota -- keeps the normal workflow, just over WiFi
PLATFORMIO_UPLOAD_PORT=mask-cam.local PLATFORMIO_UPLOAD_FLAGS="--auth=$OTA_PASSWORD" \
  ~/.platformio/penv/bin/pio run -e mask-cam -t upload

# 2. the web route -- a file picker under "firmware" at http://mask-cam.local/
#    or by hand:
curl -X POST -H "X-OTA-Key: $OTA_PASSWORD" \
     --data-binary @.pio/build/mask-cam/firmware.bin http://mask-cam.local/update
```

**The web route is ~10× faster** — 6.6 s at 146–162 kB/s against espota's 63 s for the same
image, because espota acknowledges every chunk. Use espota when you want one command; use
the web form from a phone, or when there is no toolchain to hand.

**Why it cannot brick the mask.** `Update` writes to the **inactive** app slot and only
flips `otadata` once the whole image has arrived and its checksum verifies. A dropped
upload leaves the running firmware exactly where it was. Verified deliberately rather than
assumed: killing an upload at ~30 % left the same build in the same slot, still recording,
with `ota_err` reading `connection dropped mid-upload`.

**What it stands down first, and in this order:** the recorder (and it *waits* for the clip
to close — an AVI whose header was never patched will not play, so rebooting mid-clip
throws away the last minute for nothing), then the camera pump (writing flash stalls the
cache, and camera DMA plus PSRAM traffic through a stalled cache is how you get a corrupt
frame or a watchdog), then the detector. On a failed update all three come back by
themselves.

`/health` reports `fw_build`, `fw_part` (`app0`/`app1`) and `ota_auth`, which is how you
confirm an update actually landed — **the slot flips**.

⚠️ `OTA_PASSWORD` lives in `secrets.h` and gates **both** routes. Without it anyone on the
network can replace the firmware, and the UI and boot log both say so. This is plain HTTP
on your own LAN: the password is not encrypted in transit, it only stops the casual case.

**Verified end to end, 2026-08-21:** espota `app0 → app1`; the web route `app1 → app0`;
wrong password → 401; a 19-byte body → 400 without erasing anything; an aborted upload
survived with the running firmware intact and the camera resumed. The last of those fixes
— an error message that used to read `update failed: No Error` when the *socket* died —
was itself shipped to the board over the air.

## Motion detection — Phase 1: it annotates, it does not gate

The ring records everything exactly as before. The detector only writes events
beside the footage, into `/motion.log`, each one naming the clip **and the offset
into it**. A wrong threshold therefore costs a wrong label, never footage — which
matters when the thing being tuned is behind a screwed-down cover.

```
GET /motion?n=40     recent events, newest first
GET /motion?clear=1  wipe the log
```
```json
{"t":"2026-08-21 15:51:04","clip":"001400000_20260821-155006.avi",
 "into":55,"blocks":3,"total":108,"lum":53}
```

**How it works, and why each piece is there:**

- **Decode at `JPG_SCALE_8X` only.** SVGA → 100×75, **39 ms measured on this board**
  (and 39 ms again under live streaming + recording, not just on the bench). The
  other scales cost ~310–340 ms because only 1/8 skips the IDCT — see
  "Benchmarks" below. At 2 Hz this is ~8 % of one core.
- **Straight to grayscale in the decode callback**, so the 1.44 MB RGB888 image is
  never materialised at all.
- **Count changed 8×8 blocks, never summed difference.** A 5 % brightness step and
  a person occupying 5 % of frame are *numerically identical* under sum-of-absolute-
  difference. Counting blocks separates them — and only a block count makes the
  next item possible.
- **Reject changes that are too global.** Above `mot_pct` (60 %) of blocks changed,
  it is lighting or the AEC, never a person. This is the single highest-value
  false-positive defence there is, and only two projects in the wild implement it.
- **A second, cheaper veto**: the OV3660's overall luminance register `0x56A1`,
  **0.65 ms** per read. Useless as a detector — it is one global number — which is
  exactly what makes it a lighting-change detector. Measured as a *percentage*,
  because the value is linear-domain and compresses into single digits in a dark
  room.
- **Rebaseline immediately** after any rejected change, or the lighting step trails
  into the next comparison as fake motion.
- **Two consecutive hits** (1 s at 2 Hz), a 15 s warm-up while AEC/AWB settle, and
  a 5 s cooldown so one person walking through is one event.

**Verified on the board, 2026-08-21:** the trigger path end-to-end (forced sensitive,
events logged with clip and offset, cooldown spacing them exactly 5 s apart); the
global rejector (a 2 % ceiling turned sensor noise into 14 rejections and no events);
and no effect on recording — still 10.0 fps, still 56 °C. Dropping JPEG quality from
12 to 30 changed **0 of 108 blocks**, so the 8×8 averaging at 1/8 scale is inherently
immune to compression artefacts.

**Not verified: whether it discriminates real motion.** That needs a person walking
past, and it is the entire point of Phase 1 — run it for a week, read `/motion.log`,
and tune `mot_diff` / `mot_min` / `mot_pct` live from the UI without reflashing.

⚠ Expect a **TV or monitor in frame to trigger constantly.** A screen is *genuine*
pixel motion; no frame-differencing detector rejects it. That needs region masking,
which Phase 1 does not have.

## Benchmarks — `pio run -e bench`

Two numbers this design hinged on, measured here rather than taken from the web.

**Decode cost.** It is a cliff, not a slope — only 1/8 skips the IDCT:

| scale | out | SVGA | UXGA |
|---|---|---|---|
| **1/8** | 100×75 | **39.4 ms** | 151.9 ms |
| 1/4 | 200×150 | 307.9 ms | 1226 ms |
| 1/2 | 400×300 | 341.3 ms | 1362 ms |
| 1/1 | 800×600 | 310.9 ms | 1241 ms |

So there is exactly one usable scale for detection, and it is cheap enough that no
JPEG-length prefilter is needed to avoid it.

**The OV3660's 4×4 zone map at `0x5691–0x56A0` is real** — it reads back correlating
**+0.968** with the decoded image's own zone means, and tracks a forced exposure sweep
monotonically in both directions. As far as the research found, no ESP32 project reads
it. **But it is not the free pre-gate it looks like:** 17 SCCB reads take **11.0 ms**,
not the sub-millisecond the datasheet arithmetic suggests, because SCCB runs at 100 kHz
and that is fixed in the prebuilt SDK. Sixteen numbers for 11 ms against 7 500 pixels
for 39 ms is a bad trade, so only the single overall register survives, as the veto
above.

*(The first stimulus tried was the GPIO3 flashlight. It moved neither the registers nor
the decoded image, so it tested the LED, not the sensor. Exposure is a stimulus that
cannot fail.)*

## Testing the ring

The card holds ~30 hours, so waiting for it to fill is not a test. The water marks are
overridable from the build — set the target just below what is actually free and the ring
runs in seconds:

```bash
FREE=$(curl -s http://mask-cam.local/health | python3 -c "import json,sys;print(json.load(sys.stdin)['card_free_mb'])")
PLATFORMIO_BUILD_FLAGS="-DMC_FREE_TARGET_MB=$((FREE-4)) -DMC_FREE_FLOOR_MB=$((FREE-40)) -DMC_CLIP_SECONDS=10" \
  ~/.platformio/penv/bin/pio run -e mask-cam -t upload
```

Done here on 2026-08-21: it settled into deleting exactly one clip per clip written, oldest
first, in strict sequence order, holding 10.0 fps throughout — and it deleted the previous
boot's clips before the current boot's, which is the ordering the sequence prefix exists
for. **Reflash without the flags afterwards.**

### ⚠ The radio is the bottleneck, not the board

At **−76 dBm** — the bench, one floor from the AP — the numbers are sobering:

| | |
|---|---|
| live stream | ~2.7 fps of the 10 the sensor is producing |
| clip download | **~25 kB/s**, so a 14 MB clip takes about nine minutes |

Nothing in the firmware is the limit here; the camera holds 10.0 fps throughout and the
card takes it. This is signal strength, and the mask is going to hang somewhere with a
metal-free but not necessarily closer line to the AP. If the stream matters more than the
resolution, drop the framesize — VGA or QVGA in the UI costs a quarter of the bytes. If
retrieval matters, pull the card; USB is ten times faster than this link.

## Things that will waste your time if you rediscover them

- **`board_build.arduino.memory_type = qio_opi`, and do not "tidy" it.** The flash is quad
  but the PSRAM is octal. Set it to `qio_qspi` and PSRAM comes back zero, the camera
  silently refuses any framesize above SVGA, and nothing says why.
- **`ARDUINO_USB_MODE=1` + `ARDUINO_USB_CDC_ON_BOOT=1` are load-bearing.** The USB-C goes
  to the S3's native USB. Without these, `Serial` goes to UART0 — which is not wired to
  anything you can see, so a perfectly working board looks dead.
- **The microSD has only CMD/CLK/DAT0 wired.** 1-bit is not a fallback, it is the only
  mode. `SD_MMC.begin()` with its 4-bit default fails for a reason that has nothing to do
  with the card.
- **`pio device monitor` needs a TTY** — `termios.error: Inappropriate ioctl for device` is
  the monitor failing, not the board. `tools/board.py` exists for this.
- **A capture that returns a buffer is not a capture that returns a picture.** A dead data
  line still hands back a structurally valid, entirely black JPEG. The selftest checks the
  SOI marker and a plausible length; your eyes check the rest.
- **The fallback clip counter used to restart at 1 on every boot** and overwrote
  `clip0001.avi` without a word. It now asks the card what already exists. If NTP answers,
  clips are named by wall-clock time and the question does not arise.
- **This IDF's `esp_http_server` has no `HTTPD_503_SERVICE_UNAVAILABLE`.** Set the status
  line by hand, or tell a viewer the mask is broken when it is merely busy.
- **`WiFi.setSleep(true)` makes the board effectively unreachable.** Modem sleep parks the
  radio between beacons; measured here, it turned a ping into **306–1244 ms** and HTTP
  would not complete at all. With it off the same link answers in ~117 ms. It also saves
  nothing in the case that matters, because streaming keeps the radio busy anyway. This
  was a deliberate choice for heat, and the measurement overruled it.
- **`HWCDC::write()` returns a SHORT count when the host stops reading, and every `Print`
  method throws that return value away.** This silently lost 16 kB out of the middle of a
  4 MB USB dump — producing a file that still opened and still played. Anything that
  pushes bulk data over USB has to loop on the return value; `serial_write_all()` does.
  `tools/board.py clip` checks the byte count against the size the board announced, and
  the board says `---ABORTED FILE---` rather than `---END FILE---` if it gave up.
- **Never order clips by wall-clock anything.** Ring mode deletes the oldest, so "which is
  oldest" must be answerable in the seconds after boot when there is no clock. By filename,
  two naming schemes coexist and `"20260821-…" < "clip0001.avi"` because `'2' < 'c'` — the
  ring eats the newest first. By mtime, every boot's first clip carries 1970 and is deleted
  first, and that is the moment the power came back. Both were tried; both were wrong. The
  sequence prefix is the fix, and it costs one NVS write per boot.
- **`File::flush()` is what makes a file exist.** Without it the size stays 0 in the
  directory entry no matter how many megabytes have been written, and a reset loses all of
  it. This is not an AVI quirk, it is FAT.
- Under WSL the board arrives over `usbipd`. A reset re-enumerates it, and the attachment
  can drop with it.

## Open

- ⚠ **The sensor is an OV3660, and the main README's optics section assumes an OV2640.**
  The 79° unvignetted cone was checked against "a stock OV2640 lens is 65–70°". That
  conclusion probably survives — OV3660 modules ship with similar glass — but it is now an
  assumption about a part we have no number for. One photograph through the finished
  aperture retires it. The OV3660 also reaches **QXGA 2048×1536**, a step above the UXGA
  the selftest uses and available in the UI.
- **The "no clock" naming branch has never actually run.** Every reset available here keeps
  the RTC alive, so the first clip of each boot still gets a real timestamp. A cold start
  from dead battery should produce `…_noclock.avi`; that path is reasoned, not observed.
- **`paused_for_space` is untested.** It only fires if ring mode is on and housekeeping
  still cannot free room — a card full of something that is not clips. The resume path is
  written and not exercised.
- **Nothing has run on battery yet.** Streaming keeps the draw well above the DWEII boost's
  load-current threshold, which is the good case; what has not been tested is what happens
  to the queue and the card when the supply sags. Modem sleep is now off, which costs a
  few tens of milliamps at idle — worth revisiting if battery life disappoints, but not by
  simply turning it back on.
- **Signal.** −76 dBm on the bench already halves what the stream can carry. Where the mask
  actually hangs is now a networking question as well as a decorative one.
- **Heat.** 56 °C on the bench, in free air, on a desk. The bay is sealed apart from the
  cover's vent slots and the mask hangs vertically. The health page shows the die
  temperature; watch it once the cover is on.

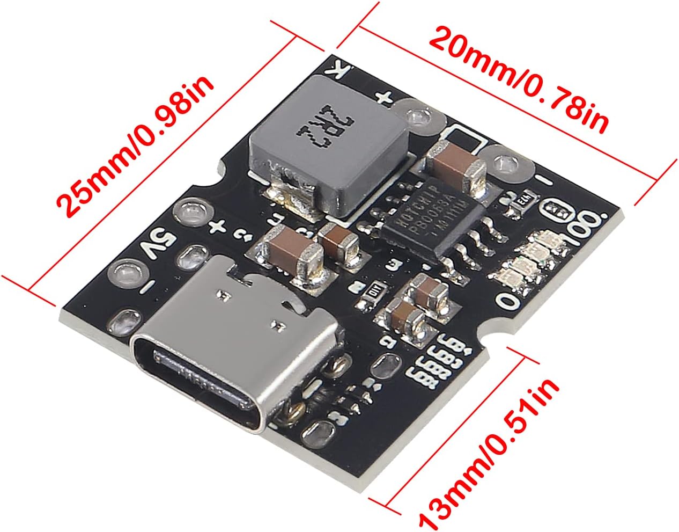
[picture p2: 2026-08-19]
dweii_spec.jpg

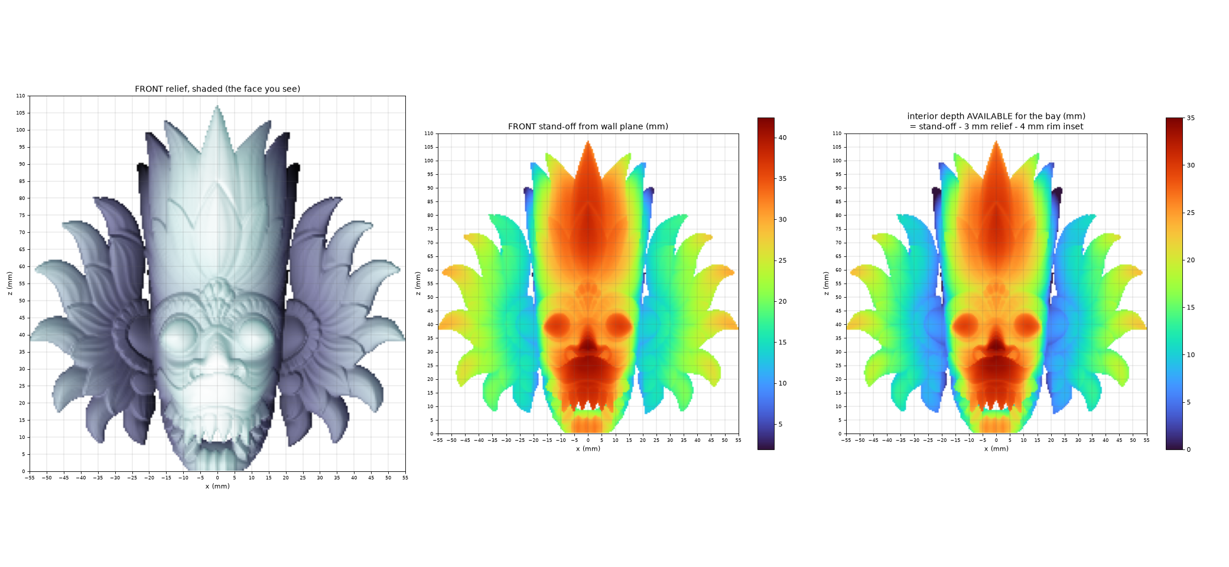
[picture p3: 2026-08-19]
face_map.png

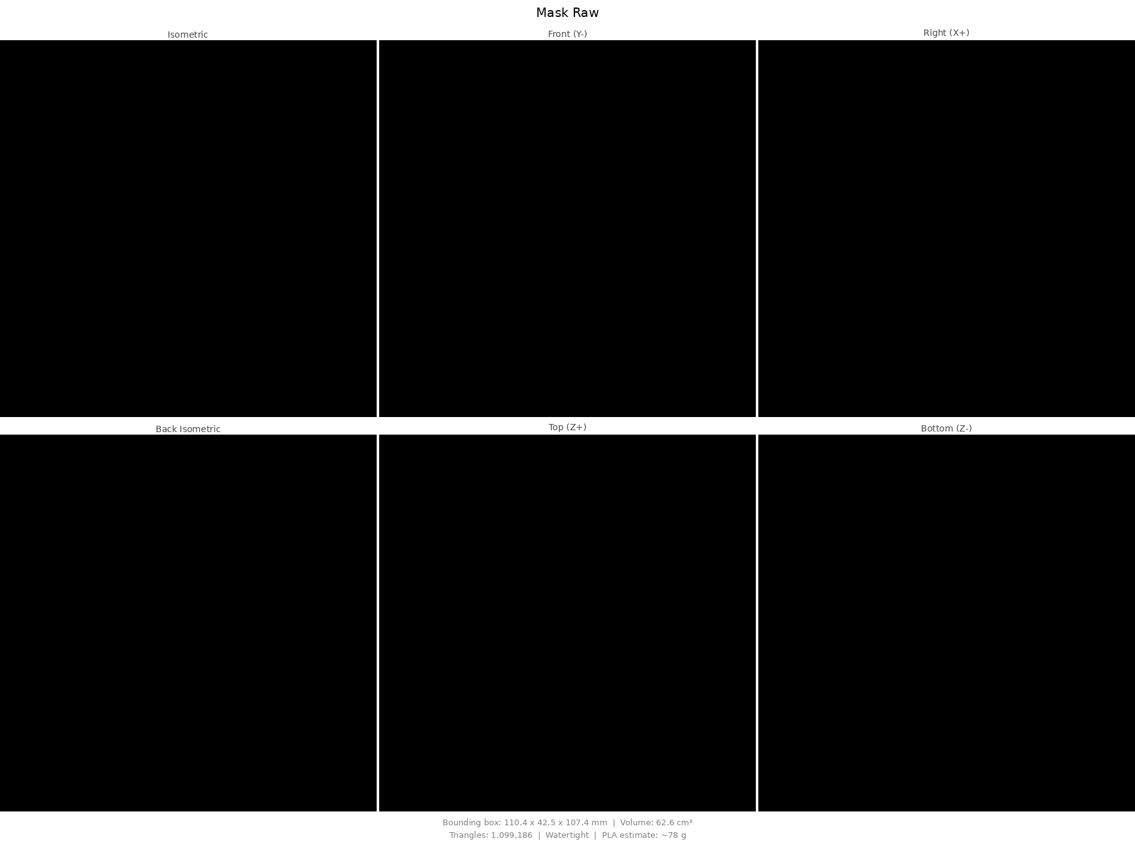
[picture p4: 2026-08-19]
mask_preview.png

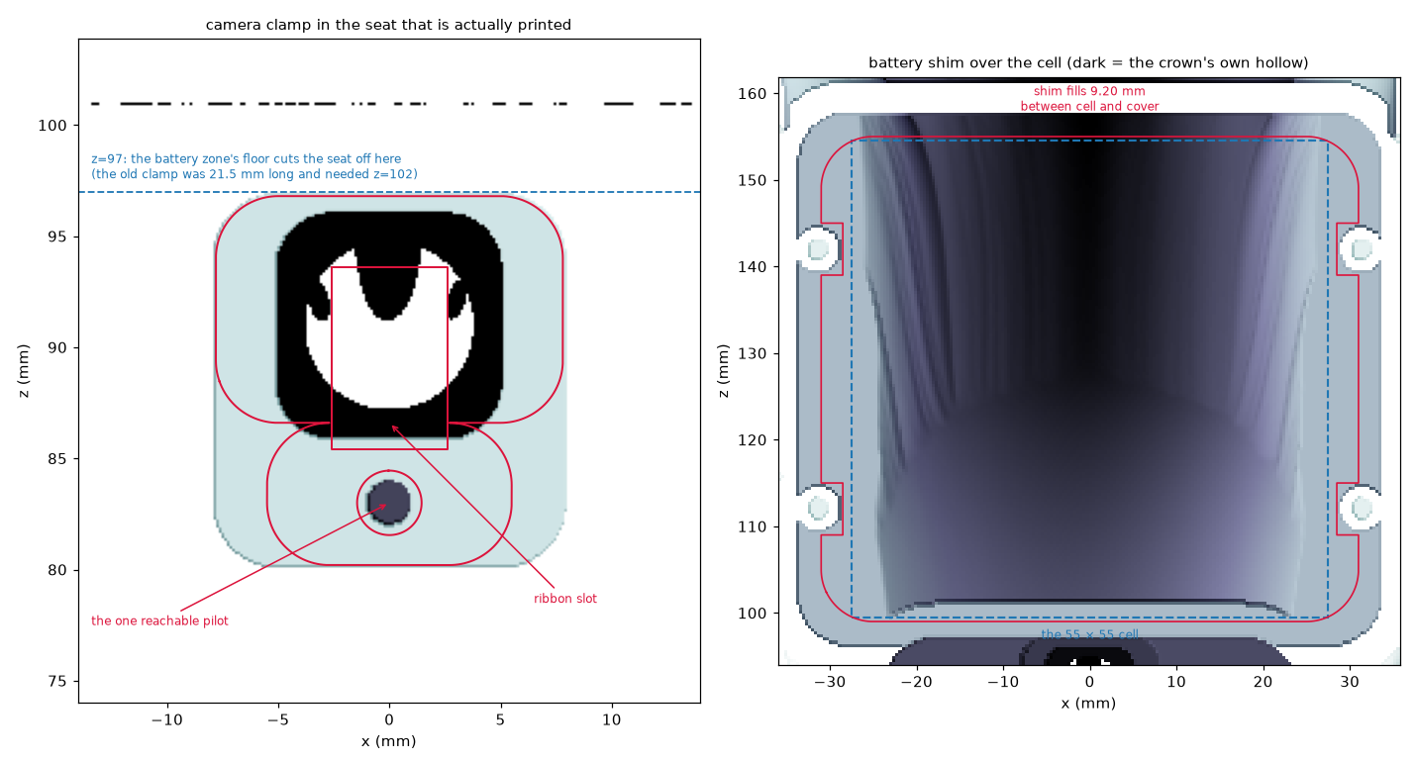
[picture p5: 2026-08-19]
smalls.png

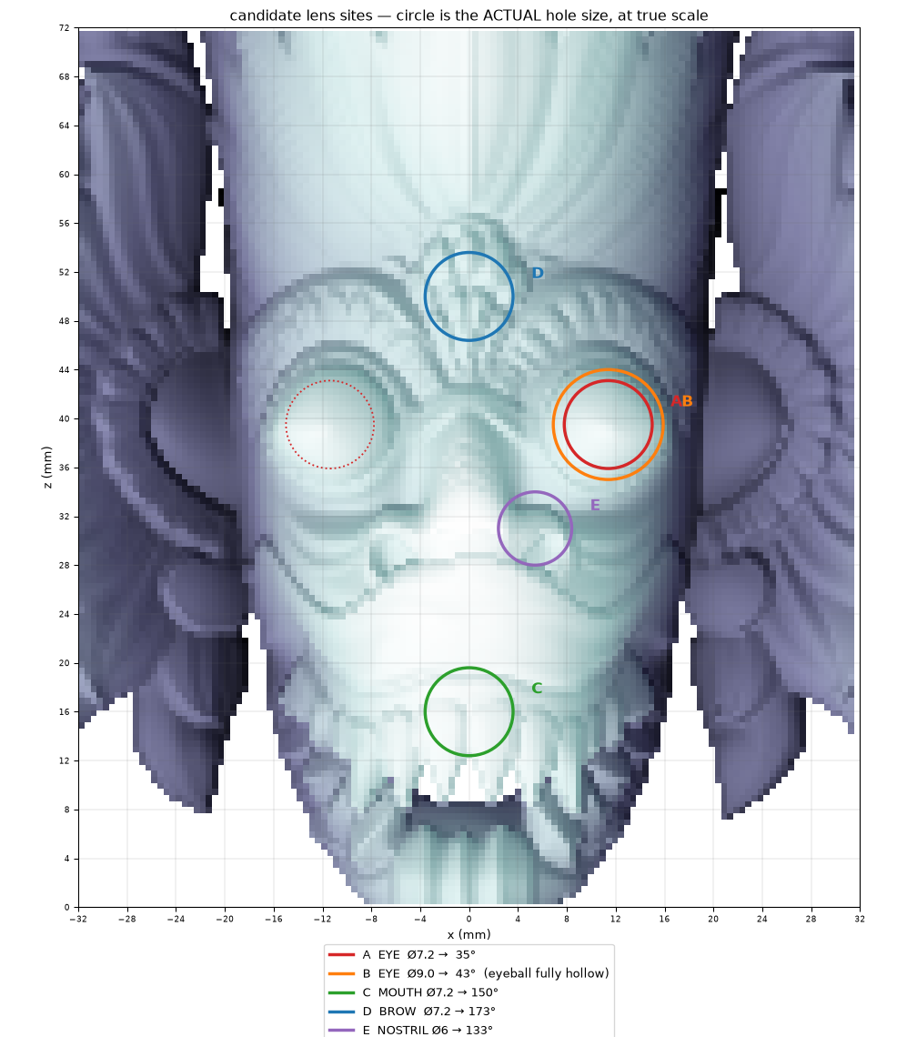
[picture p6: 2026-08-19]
sites.png

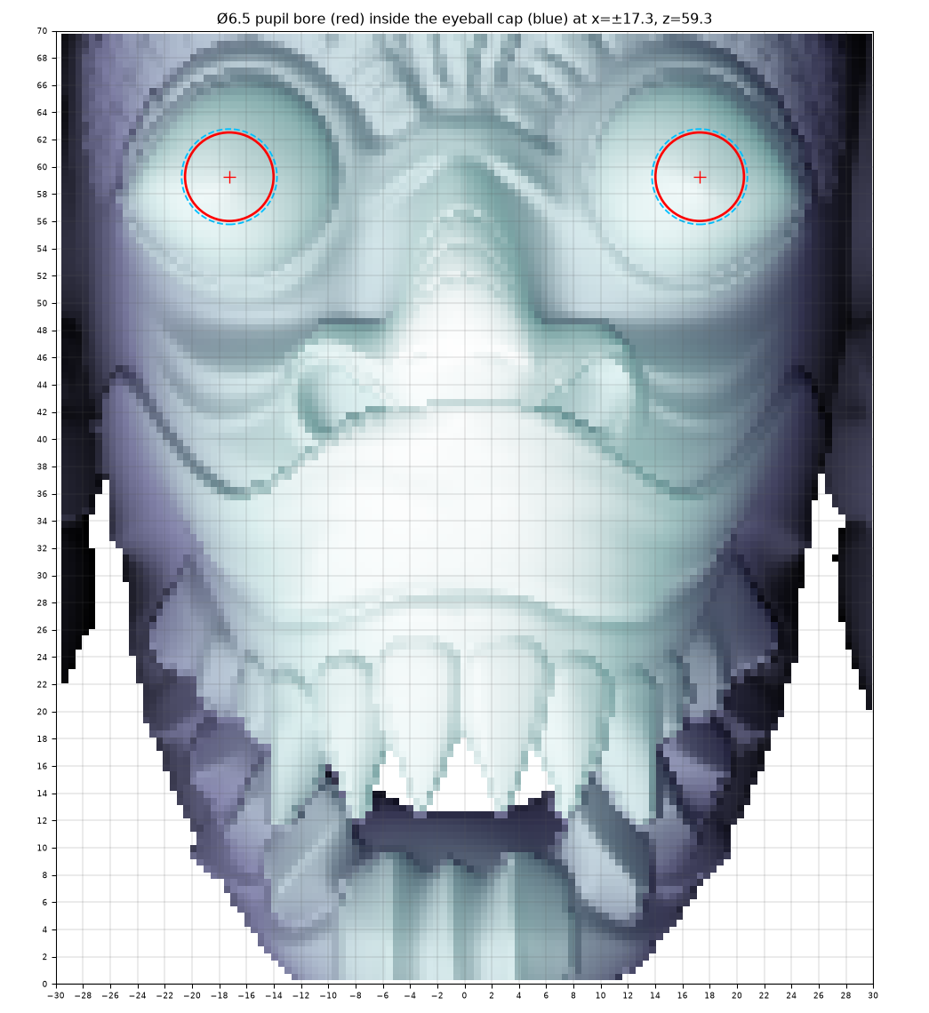
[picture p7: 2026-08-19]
eyes.png

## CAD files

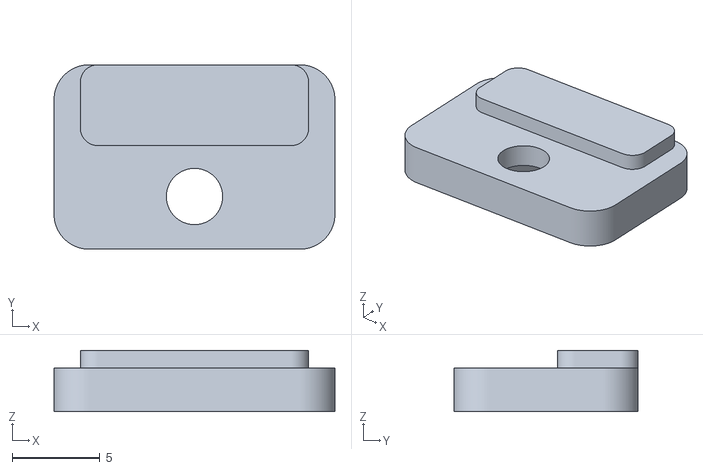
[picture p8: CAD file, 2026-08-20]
power_clamp.stl
16.0 x 10.5 x 3.50

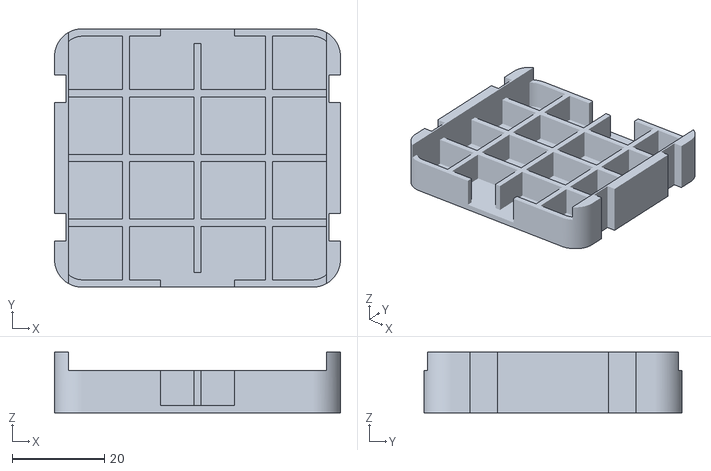
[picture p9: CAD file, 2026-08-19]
battery_shim.stl
62.0 x 56.0 x 13.2

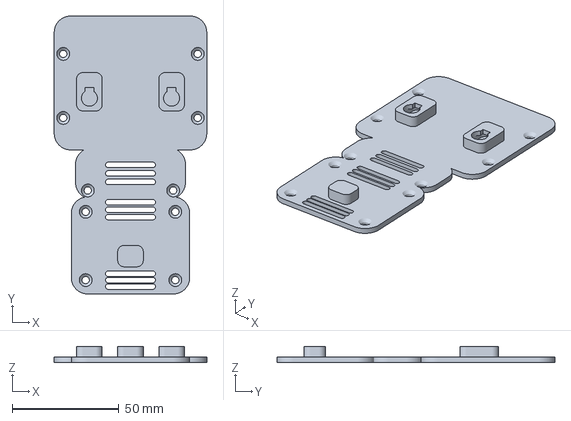
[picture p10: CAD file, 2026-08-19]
cover.3mf
71.5 x 130.2 x 7.50 mm

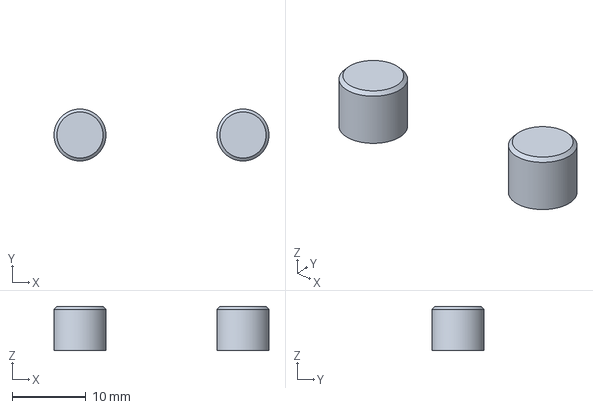
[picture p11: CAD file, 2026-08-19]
eye_plugs.3mf
29.1 x 7.05 x 6.00 mm

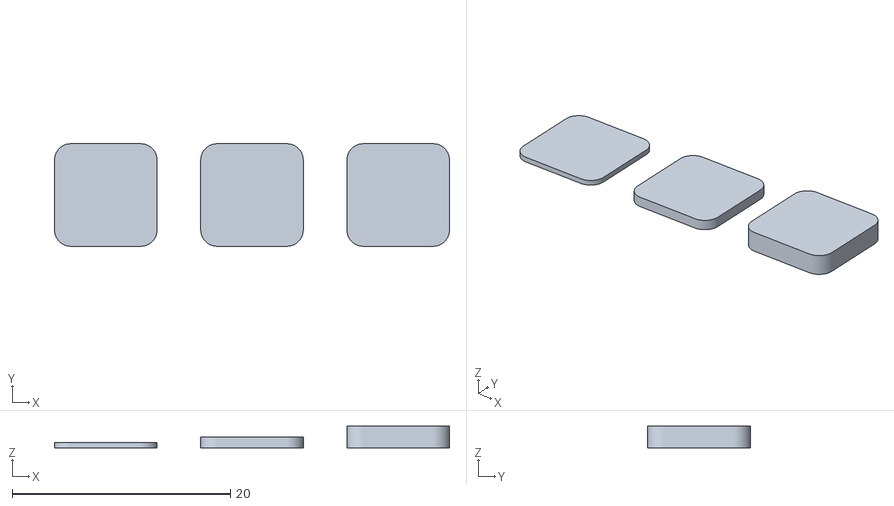
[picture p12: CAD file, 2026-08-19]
camera_shims.stl
36.2 x 9.40 x 2.00

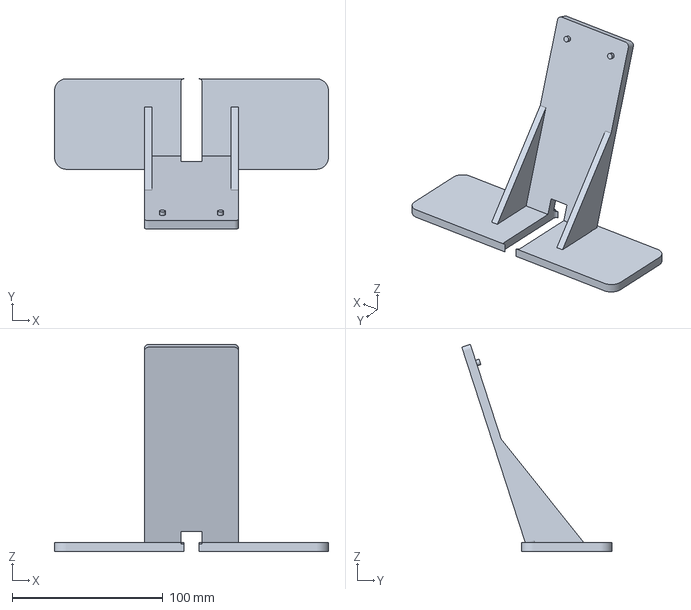
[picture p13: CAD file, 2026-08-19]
stand.3mf
181.6 x 99.7 x 137.4 mm

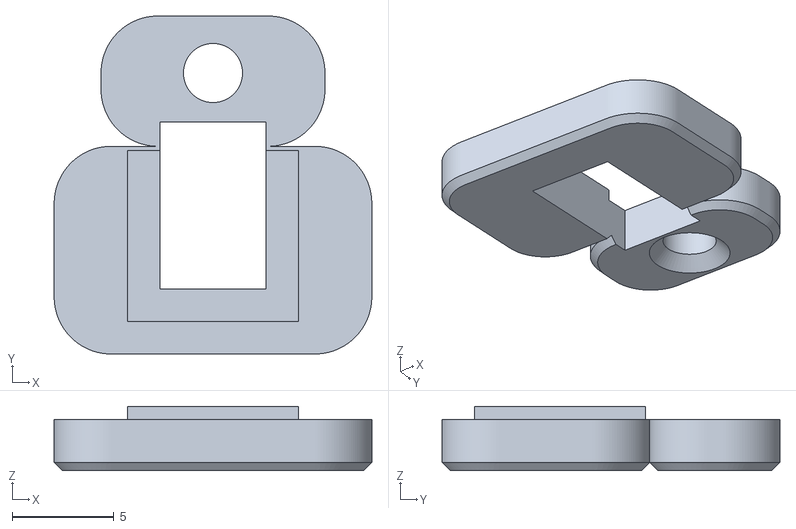
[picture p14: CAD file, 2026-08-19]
camera_clamp.stl
15.6 x 16.6 x 3.15

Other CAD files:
cover.stl
eye_plugs.stl
stand.stl

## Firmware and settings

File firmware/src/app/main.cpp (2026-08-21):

// main.cpp — mask-cam application firmware.
//
// A camera sealed inside a wall-hung mask: live MJPEG on the LAN, MJPEG AVI
// clips onto the microSD, and a web UI to arm and disarm the recording.
//
// If something here misbehaves, flash the OTHER environment first:
//
//     pio run -e selftest -t upload
//
// That one answers "is the hardware even working" in twenty seconds, and it is
// much easier to read than a fault three layers into a streaming server.

#include <Arduino.h>
#include <WiFi.h>
#include <ESPmDNS.h>
#include <time.h>

#include "../board_pins.h"
#include "../config.h"
#include "capture.h"
#include "recorder.h"
#include "web.h"
#include "detect.h"
#include "ota.h"

// The one file that is not in the repository. Fail loudly and usefully rather
// than with forty lines of "WIFI_SSID was not declared in this scope".
#if defined(__has_include)
#  if __has_include("../secrets.h")
#    include "../secrets.h"
#  else
#    error "firmware/src/secrets.h is missing. cp src/secrets.h.example src/secrets.h and fill in your WiFi."
#  endif
#else
#  include "../secrets.h"
#endif

static bool wifi_up = false;

// --- USB console -----------------------------------------------------------
// Everything the web UI can do, reachable over the wire. This is not a
// debugging luxury: the board finishes up behind a screwed-down cover, and the
// day WiFi is the thing that broke is the day you need another way in.

static void console_status() {
  CapStats c; capture_stats(&c);
  RecStats s; recorder_stats(&s);
  Serial.printf("camera  %s  %ux%u  %.1f fps (target %u)  %u frames, %u fails\n",
                capture_sensor_name(), c.width, c.height, c.fps_actual,
                c.fps_target, c.frames, c.fails);
  Serial.printf("record  %s  %s  %u frames  %.2f MB\n",
                s.armed ? "ARMED" : (s.paused_for_space ? "PAUSED (no room)" : "idle"),
                s.clip[0] ? s.clip : "-",
                s.clip_frames, s.clip_bytes / 1048576.0);
  Serial.printf("card    %llu MB free of %llu  |  %u written, %u ring-deleted  |  write %u/%u ms\n",
                (unsigned long long)s.card_free_mb, (unsigned long long)s.card_total_mb,
                s.clips_written, s.clips_deleted, s.write_ms_last, s.write_ms_max);
  Serial.printf("ring    %s\n", s.ring ? "ON -- oldest clips are deleted to make room"
                                        : "off -- recording stops when the card fills");
  Serial.printf("queue   %u/%u slots in use  |  %u frames dropped\n",
                s.queue_depth, MC_REC_QUEUE_SLOTS, s.frames_dropped);
  Serial.printf("net     %s  %s  rssi %d\n",
                wifi_up ? "up" : "DOWN", WiFi.localIP().toString().c_str(), WiFi.RSSI());
  Serial.printf("health  %.0f C  heap %u  psram %u  up %lus\n",
                temperatureRead(), (unsigned)ESP.getFreeHeap(),
                (unsigned)ESP.getFreePsram(), (unsigned long)(millis() / 1000));
  OtaStats o; ota_stats(&o);
  Serial.printf("fw      built %s %s, running from '%s'%s\n", __DATE__, __TIME__,
                o.running_part, o.active ? "  [OTA IN PROGRESS]" : "");
  MotStats m; motion_stats(&m);
  Serial.printf("motion  %s  %u checks, %u events, %u rejected as lighting\n",
                m.enabled ? (m.running ? "on" : "starting") : "OFF",
                m.checks, m.events, m.rejected_global);
  Serial.printf("        last %u/%u blocks, decode %u ms, lum %u%s\n",
                m.last_blocks, m.total_blocks, m.last_decode_ms, m.last_lum,
                m.last_global ? "  [rejected: whole-scene change]" : "");
  if (m.last_event[0]) Serial.printf("        last event: %s\n", m.last_event);
  if (s.last_error[0]) Serial.printf("error   %s\n", s.last_error);
}

static void console(char c) {
  switch (c) {
    case 's': console_status(); break;
    case 'r':
      if (recorder_armed()) { recorder_disarm(); Serial.println("recording stopped"); }
      else                  { recorder_arm();    Serial.println("recording started"); }
      break;
    case 'l': recorder_print_listing(); break;
    case 'm': {                       // recent motion events
      Serial.println(recorder_motion_json(15));
      break;
    }
    case 'd': {                       // dump the newest clip, base64
      char name[64];
      if (recorder_newest_clip(name, sizeof(name))) recorder_dump_base64(name);
      else Serial.println("no clips yet");
      break;
    }
    case '?':
      Serial.println("s status  r record on/off  l list clips  d dump newest clip"
                     "  m motion log");
      break;
    default: break;
  }
}

static void wifi_connect() {
  WiFi.persistent(false);
  WiFi.mode(WIFI_STA);
  WiFi.setHostname(MC_HOSTNAME);
  // Modem sleep OFF, and this was measured rather than assumed. With it on,
  // the board answered a ping in 306-1244 ms and HTTP would not complete at
  // all: the radio parks between beacons, and on a weak link it misses them.
  // It also saves nothing in the case that matters -- streaming keeps the
  // radio busy continuously. The cost is a few tens of milliamps at idle.
  WiFi.setSleep(false);
  WiFi.begin(WIFI_SSID, WIFI_PASS);

  Serial.printf("[net] joining \"%s\"", WIFI_SSID);
  uint32_t t0 = millis();
  while (WiFi.status() != WL_CONNECTED && millis() - t0 < 20000) {
    delay(300);
    Serial.print(".");
  }
  Serial.println();

  wifi_up = WiFi.status() == WL_CONNECTED;
  if (!wifi_up) {
    Serial.println("[net] no join. Check SSID/password in src/secrets.h --");
    Serial.println("[net] the S3 has no 5 GHz radio, so a 5 GHz-only SSID will never appear.");
    return;
  }

  Serial.printf("[net] %s  rssi %d dBm\n", WiFi.localIP().toString().c_str(), WiFi.RSSI());

  if (MDNS.begin(MC_HOSTNAME)) {
    MDNS.addService("http", "tcp", MC_HTTP_PORT);
    Serial.printf("[net] http://%s.local/\n", MC_HOSTNAME);
  }

  // Clips are named by wall-clock time when there is one. Not fatal if NTP is
  // unreachable -- the recorder falls back to a counter.
  configTime(0, 0, "pool.ntp.org", "time.nist.gov");
}

void setup() {
  // GPIO3 is the flashlight. Kill it FIRST and leave it dead: this board ends
  // up sealed inside a mask whose cover vents leak light both ways, and there
  // is no reason for it ever to come on.
  pinMode(PIN_FLASH_LED, OUTPUT);
  digitalWrite(PIN_FLASH_LED, LOW);

  Serial.begin(115200);
  uint32_t t0 = millis();
  while (!Serial && millis() - t0 < 2000) delay(10);

  Serial.println("\n\n=== mask-cam ===");
  Serial.printf("built %s %s\n", __DATE__, __TIME__);
  Serial.printf("psram %u bytes\n", (unsigned)ESP.getPsramSize());

  if (!capture_begin()) {
    Serial.println("!! camera did not start. Flash the selftest environment.");
    // No reboot loop: a board that reboots forever is a board you cannot talk
    // to. Sit here so the serial console still says what happened.
    while (true) delay(1000);
  }

  if (recorder_begin()) {
    recorder_start_writer();
    recorder_start_housekeeper();
    // Armed here, and the capture pump starts before the network below, so
    // the first frame is on the card seconds after power -- not twenty
    // seconds later when the join finishes. On a cold start there is no clock
    // yet, so that first clip is named "noclock"; its sequence number still
    // places it correctly against everything else on the card.
    if (MC_RECORD_ON_BOOT && recorder_arm())
      Serial.println("[rec] armed on boot");
  } else {
    Serial.println("!! no microSD. Streaming will work; recording will not.");
  }

  // The pump goes BEFORE the network, and this is the whole point of arming on
  // boot. Joining a WiFi network takes twenty seconds when it works and twenty
  // seconds when it does not, and no frame exists until the pump is running --
  // so starting it after the join threw away exactly the moment that recording
  // on boot is meant to catch. Nothing here needs an IP address.
  capture_start_pump();

  // The detector rides on the pump's published frames, so it goes up after it
  // and before the network -- nothing here needs an IP either.
  if (motion_begin()) motion_start_task();

  wifi_connect();

  if (!web_begin())
    Serial.println("!! http server did not start");

  // Last, because it needs the network. Once the cover is on, this is the only
  // way firmware ever changes again.
  ota_begin();

  Serial.println("ready.  ? for the console commands\n");
}

void loop() {
  static uint32_t last_beat = 0, last_net = 0;

  // WiFi drops happen, and this thing is behind a screwed-down cover. Notice,
  // and rejoin, without taking the camera or the recorder down with it.
  if (millis() - last_net > 10000) {
    last_net = millis();
    if (WiFi.status() != WL_CONNECTED) {
      Serial.println("[net] link lost, reconnecting");
      WiFi.reconnect();
    }
  }

  while (Serial.available()) console(Serial.read());

  if (millis() - last_beat > 30000) {
    last_beat = millis();
    CapStats c; capture_stats(&c);
    RecStats s; recorder_stats(&s);
    Serial.printf("[%lus] %ux%u %.1f fps | %s | card %llu MB free | %.0f C | heap %u\n",
                  (unsigned long)(millis() / 1000), c.width, c.height, c.fps_actual,
                  s.armed ? s.clip : "idle",
                  (unsigned long long)s.card_free_mb,
                  temperatureRead(), (unsigned)ESP.getFreeHeap());
  }

  delay(200);
}

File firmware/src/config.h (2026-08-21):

// config.h — the knobs, in one place, with the reasoning attached.
//
// Defaults chosen for a camera sealed inside a wall-hung mask, where the two
// things that can actually hurt are HEAT (the bay is closed apart from the
// cover's vent slots) and a CARD THAT FILLS UP while nobody is watching.
#pragma once

#include <esp_camera.h>

// --- identity --------------------------------------------------------------
#define MC_HOSTNAME     "mask-cam"        // -> http://mask-cam.local/
#define MC_HTTP_PORT    80
#define MC_STREAM_PORT  81                // the stream gets its own server, see web.cpp

// --- capture ---------------------------------------------------------------
// One sensor, so the stream and the recording share a framesize. SVGA is the
// balance point: an OV3660 frame at quality 12 lands around 40 kB, which is
// ~1.4 GB/hour at 10 fps -- about 22 hours on the 32 GB card. UXGA looks
// better and fills the card in four.
#define MC_DEFAULT_FRAMESIZE  FRAMESIZE_SVGA   // 800x600
#define MC_DEFAULT_QUALITY    12               // 0 best .. 63 worst
#define MC_DEFAULT_FPS        10

// Image orientation. The camera module ends up clamped into the mask's pocket
// lens-forward, which puts the sensor in upside down -- the bench image came
// out inverted, scene and all.
//
// A 180 degree rotation needs BOTH axes. Setting only vflip turns the picture
// the right way up and leaves it MIRRORED, which is the sort of thing you do
// not notice until you try to read something in the footage.
//
// These are only the defaults: the live values are kept in NVS, so whatever
// you settle on in the UI survives a reboot, a power cut and an OTA.
#define MC_DEFAULT_VFLIP      1
#define MC_DEFAULT_HMIRROR    1

// The sensor can go to QXGA (2048x1536) -- it is an OV3660, not the OV2640 the
// main README's optics section assumes. Left available, not default.
#define MC_MAX_FRAMESIZE      FRAMESIZE_QXGA

// A generous upper bound on one JPEG, so every buffer that has to hold a frame
// is sized once rather than grown mid-stream. UXGA at quality 8 peaks near
// 200 kB; QXGA near 350 kB.
#define MC_MAX_FRAME_BYTES    (400 * 1024)

// --- recording -------------------------------------------------------------
// Clips rather than one endless file: a power cut truncates the clip being
// written and nothing else. 60 s also keeps the in-memory AVI index small.
// How often an open clip is made real on the card -- header sizes patched and
// the directory entry synced. This is the worst case a power cut can cost you.
#define MC_SYNC_SECONDS       5

#ifndef MC_CLIP_SECONDS
#  define MC_CLIP_SECONDS     60
#endif
#define MC_REC_DIR            "/DCIM"

// This is a set-and-forget wall camera: it arms itself as soon as the card is
// mounted, so a power cut cannot leave it streaming happily and recording
// nothing. Turn it off here if you would rather press the button yourself.
#define MC_RECORD_ON_BOOT     true

// Ring mode -- delete the oldest clip to make room -- is ON to match. The card
// then holds a rolling window, roughly 30 hours at SVGA/10 fps, and never
// fills. This DESTROYS the oldest footage by design; the UI says so and the
// checkbox turns it off.
#define MC_DEFAULT_RING       true

// Two water marks, not one.
//   TARGET  housekeeping keeps free space above this, deleting oldest first.
//   FLOOR   the writer's hard stop, if housekeeping ever falls behind.
// Keeping them apart means deletion happens on a background task, well before
// the recorder is in trouble, instead of in the middle of a frame write.
// Overridable from the build so the ring can be exercised on demand: setting
// TARGET just below the card's free space makes it fill in seconds instead of
// thirty hours. See firmware/README.md, "Testing the ring".
#ifndef MC_FREE_TARGET_MB
#  define MC_FREE_TARGET_MB   512
#endif
#ifndef MC_FREE_FLOOR_MB
#  define MC_FREE_FLOOR_MB    256
#endif

// Deleting scans the directory, and a 29 GB card holds ~1800 clips. Doing that
// once per deletion would put a long directory walk between frames every
// minute, so a scan collects this many victims at once and the next fifteen
// deletions are free.
#define MC_RING_BATCH         16

// Frames waiting to go onto the card. MEASURED on this board: a single SD
// write in 1-bit mode usually takes a few ms but spikes to 240. With the write
// on the capture path that spike is a visible stutter in the live view, so the
// card gets its own task and this queue absorbs the spikes. Four slots at SVGA
// covers ~400 ms of stall; each slot costs one max-size frame of PSRAM.
#define MC_REC_QUEUE_SLOTS    4

// A 60 s clip at 30 fps is 1800 frames; the index is 16 bytes each. Capped so
// a runaway clip cannot eat PSRAM.
#define MC_MAX_CLIP_FRAMES    4000
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

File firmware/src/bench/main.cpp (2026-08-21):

// bench/main.cpp — two measurements, so motion detection can be designed from
// numbers off this board instead of numbers off the internet.
//
// A: what does decoding one of our JPEGs actually cost, at each scale?
//    Every published figure for this is either a different resolution, a
//    different chip, or arithmetic. The answer decides whether detection at
//    2 Hz costs 10 % of a core or 25 %.
//
// B: does the OV3660's 4x4 zone-average block (registers 0x5691-0x56A0) work?
//    The datasheet documents it, the driver already initialises the zone
//    weights, and no ESP32 project appears to read it. If it works it is a
//    sub-millisecond motion pre-gate that needs no decode at all.
//
//    It is checked against the decoded image rather than against a hand waved
//    at the lens: decode the same frame, compute its own 4x4 zone means, and
//    see whether the two agree. Agreement is the proof; nothing else is.

#include <Arduino.h>
#include <esp_camera.h>
#include <esp_jpg_decode.h>
#include <esp_heap_caps.h>
#include <esp_timer.h>

#include "../board_pins.h"

// --- a grayscale writer for esp_jpg_decode ---------------------------------
// The ROM tjpgd hands back RGB888 blocks. Converting to grayscale in the
// callback means the big RGB image is never materialised -- this is the trick
// MJPEG2SD and Tasmota both use.

struct GrayCtx {
  const uint8_t *jpeg;
  uint8_t *gray;
  uint16_t w, h;
};

static size_t rd_cb(void *arg, size_t index, uint8_t *buf, size_t len) {
  GrayCtx *c = (GrayCtx *)arg;
  if (buf) memcpy(buf, c->jpeg + index, len);
  return len;
}

static bool gray_cb(void *arg, uint16_t x, uint16_t y, uint16_t w, uint16_t h, uint8_t *data) {
  GrayCtx *c = (GrayCtx *)arg;
  if (!data) {                       // start (x==y==0, w/h = output size) or end
    if (x == 0 && y == 0) { c->w = w; c->h = h; }
    return true;
  }
  for (uint16_t j = 0; j < h; j++) {
    for (uint16_t i = 0; i < w; i++) {
      const uint8_t *p = data + ((j * w + i) * 3);
      c->gray[(y + j) * c->w + (x + i)] = (uint8_t)((p[0] + p[1] + p[2]) / 3);
    }
  }
  return true;
}

static uint8_t *gray_buf = nullptr;
static uint8_t *jpeg_copy = nullptr;

// --- B: the sensor's own 4x4 luminance map ---------------------------------

static bool read_zones(uint8_t z[16], uint8_t *overall, uint32_t *micros_taken) {
  sensor_t *s = esp_camera_sensor_get();
  if (!s) return false;
  int64_t t0 = esp_timer_get_time();
  for (int i = 0; i < 16; i++) {
    int v = s->get_reg(s, 0x5691 + i, 0xFF);
    if (v < 0) return false;
    z[i] = (uint8_t)v;
  }
  int ov = s->get_reg(s, 0x56A1, 0xFF);
  *micros_taken = (uint32_t)(esp_timer_get_time() - t0);
  if (ov < 0) return false;
  *overall = (uint8_t)ov;
  return true;
}

static void print_grid(const char *label, const uint8_t *v) {
  Serial.printf("  %-16s", label);
  for (int r = 0; r < 4; r++) {
    for (int c = 0; c < 4; c++) Serial.printf("%4u", v[r * 4 + c]);
    Serial.print(r < 3 ? " |" : "");
  }
  Serial.println();
}

// The decoded image's own 4x4 zone means, to compare against the sensor's.
static void image_zones(const uint8_t *img, uint16_t w, uint16_t h, uint8_t out[16]) {
  for (int r = 0; r < 4; r++) {
    for (int c = 0; c < 4; c++) {
      uint32_t sum = 0, n = 0;
      for (uint16_t y = h * r / 4; y < h * (r + 1) / 4; y++)
        for (uint16_t x = w * c / 4; x < w * (c + 1) / 4; x++) { sum += img[y * w + x]; n++; }
      out[r * 4 + c] = n ? (uint8_t)(sum / n) : 0;
    }
  }
}

// Pearson correlation: are the two grids measuring the same thing?
static float correlate(const uint8_t *a, const uint8_t *b) {
  float ma = 0, mb = 0;
  for (int i = 0; i < 16; i++) { ma += a[i]; mb += b[i]; }
  ma /= 16; mb /= 16;
  float num = 0, da = 0, db = 0;
  for (int i = 0; i < 16; i++) {
    float x = a[i] - ma, y = b[i] - mb;
    num += x * y; da += x * x; db += y * y;
  }
  if (da <= 0 || db <= 0) return 0;
  return num / sqrtf(da * db);
}

// ---------------------------------------------------------------------------

static bool cam_up(framesize_t fs) {
  camera_config_t cfg = {};
  cfg.pin_pwdn = CAM_PIN_PWDN;  cfg.pin_reset = CAM_PIN_RESET;
  cfg.pin_xclk = CAM_PIN_XCLK;
  cfg.pin_sccb_sda = CAM_PIN_SIOD; cfg.pin_sccb_scl = CAM_PIN_SIOC;
  cfg.pin_d7 = CAM_PIN_D7; cfg.pin_d6 = CAM_PIN_D6;
  cfg.pin_d5 = CAM_PIN_D5; cfg.pin_d4 = CAM_PIN_D4;
  cfg.pin_d3 = CAM_PIN_D3; cfg.pin_d2 = CAM_PIN_D2;
  cfg.pin_d1 = CAM_PIN_D1; cfg.pin_d0 = CAM_PIN_D0;
  cfg.pin_vsync = CAM_PIN_VSYNC; cfg.pin_href = CAM_PIN_HREF; cfg.pin_pclk = CAM_PIN_PCLK;
  cfg.xclk_freq_hz = 20000000;
  cfg.ledc_timer = LEDC_TIMER_0; cfg.ledc_channel = LEDC_CHANNEL_0;
  cfg.pixel_format = PIXFORMAT_JPEG;
  cfg.frame_size = fs;
  cfg.jpeg_quality = 12;              // production setting
  cfg.fb_count = 2;
  cfg.fb_location = CAMERA_FB_IN_PSRAM;
  cfg.grab_mode = CAMERA_GRAB_LATEST;
  return esp_camera_init(&cfg) == ESP_OK;
}

static const char *scale_name(jpg_scale_t s) {
  switch (s) {
    case JPG_SCALE_NONE: return "1/1";
    case JPG_SCALE_2X:   return "1/2";
    case JPG_SCALE_4X:   return "1/4";
    case JPG_SCALE_8X:   return "1/8";
    default: return "?";
  }
}

// One timed decode run: N frames, at one scale.
static void bench_scale(jpg_scale_t scale, int iters) {
  uint32_t lo = 0xFFFFFFFF, hi = 0, sum = 0, jpeg_sum = 0;
  uint16_t ow = 0, oh = 0;
  int ok = 0;

  for (int i = 0; i < iters; i++) {
    camera_fb_t *fb = esp_camera_fb_get();
    if (!fb) continue;
    // Copy out first: the timing must not include waiting on the driver, and
    // holding a frame buffer across a long decode would stall the pipeline.
    memcpy(jpeg_copy, fb->buf, fb->len);
    size_t len = fb->len;
    esp_camera_fb_return(fb);

    GrayCtx ctx = { jpeg_copy, gray_buf, 0, 0 };
    int64_t t0 = esp_timer_get_time();
    esp_err_t e = esp_jpg_decode(len, scale, rd_cb, gray_cb, &ctx);
    uint32_t dt = (uint32_t)(esp_timer_get_time() - t0);
    if (e != ESP_OK) { Serial.printf("    decode failed: %s\n", esp_err_to_name(e)); continue; }

    ow = ctx.w; oh = ctx.h;
    if (dt < lo) lo = dt;
    if (dt > hi) hi = dt;
    sum += dt; jpeg_sum += len; ok++;
  }

  if (!ok) { Serial.printf("  %-4s  no frames\n", scale_name(scale)); return; }
  Serial.printf("  %-4s  %4ux%-4u  %6.1f ms mean  (%.1f min / %.1f max)   jpeg %5u B\n",
                scale_name(scale), ow, oh,
                sum / 1000.0f / ok, lo / 1000.0f, hi / 1000.0f, jpeg_sum / ok);
}

static void bench_at(framesize_t fs, const char *label) {
  esp_camera_deinit();
  delay(200);
  if (!cam_up(fs)) { Serial.printf("\n%s: camera init FAILED\n", label); return; }
  delay(600);                                   // let AEC settle

  Serial.printf("\n--- decode cost at %s ---\n", label);
  jpg_scale_t scales[] = { JPG_SCALE_8X, JPG_SCALE_4X, JPG_SCALE_2X, JPG_SCALE_NONE };
  for (int i = 0; i < 4; i++) bench_scale(scales[i], 8);
}
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

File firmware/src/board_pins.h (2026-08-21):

// board_pins.h — the nulllab / emakefun ESP32-S3-CAM pin map, in one place.
//
// Source: https://github.com/nulllaborg/esp32s3-cam (the vendor's own repo for
// this exact board).  Corroborated by the board in hand: 8 MB flash and octal
// PSRAM match what esptool reports, and GPIO3 as the flashlight matches the
// LEDs the README's cover section says leak through the vents.
//
// Nothing here is guessed.  If a pin ever has to change, change it HERE — the
// bring-up self-test reads these same symbols, so a wrong pin shows up as a
// failed capture rather than as a silently dark image.
#pragma once

// --- camera (DVP, 8-bit) ---------------------------------------------------
#define CAM_PIN_PWDN   -1   // not brought out on this board
#define CAM_PIN_RESET  -1   // ditto: sensor resets from XCLK
#define CAM_PIN_XCLK   15
#define CAM_PIN_SIOD    4   // SCCB data  (I2C-ish)
#define CAM_PIN_SIOC    5   // SCCB clock

#define CAM_PIN_D7     16
#define CAM_PIN_D6     17
#define CAM_PIN_D5     18
#define CAM_PIN_D4     12
#define CAM_PIN_D3     10
#define CAM_PIN_D2      8
#define CAM_PIN_D1      9
#define CAM_PIN_D0     11

#define CAM_PIN_VSYNC   6
#define CAM_PIN_HREF    7
#define CAM_PIN_PCLK   13

// --- microSD, SD_MMC 1-bit mode -------------------------------------------
// Only CMD/CLK/DAT0 are wired, so 1-bit is not a fallback here, it is the
// only mode.  SD_MMC.begin(..., mode1bit=true).
#define SD_PIN_CMD     38
#define SD_PIN_CLK     39
#define SD_PIN_D0      40

// --- on-board LEDs ---------------------------------------------------------
// GPIO3 drives the white flashlight LEDs.  Inside a sealed mask these are
// pure liability: the README's cover section notes they leak out through the
// vent slots.  Firmware drives this LOW and leaves it there.
#define PIN_FLASH_LED   3

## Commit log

2026-08-19 Gini Raksha camera mask: cut the small parts to the mask that is actually printed
    The camera clamp did not fit the hole it was designed for, and had one of its two
    screw holes over solid plastic. Measuring the mesh rather than re-reading the
    parameters found why, and the fix is two new parts plus a checker that can catch this
    class of mistake in future.
    THE SEAT IS SHORTER THAN IT LOOKS. CAM_SEAT_Z1 asks for z=102, but the battery zone's
    floor crosses the waist at z=97 and sits 20 mm BEHIND the seat, so the last 5 mm of it
    was cut as a sealed void inside solid plastic -- and the upper clamp pilot went into
    that void. Measured on the printed mask: the reachable seat is x +/-8.00, z
    80.02.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
    [battery_shim.stl, camera_clamp.stl, camera_shims.stl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]
2026-08-19 Build the pillars AFTER carving the bay, and give the USB-C breakout its mount
    The cover had ten screw holes and the mask had nothing to screw them into. So did the
    board: no bosses either. All 14 pillars were built correctly, unioned into the mask, and
    then deleted by the bay they stood in -- build_additions() ran before build_cuts(), and
    the zone cutters span each zone's whole footprint from its floor back to the wall plane.
    verify.py reported "all checks passed" throughout, because nothing ever asked the mesh
    whether a post was there.
    build_mask.py split into build_walls() / build_pillars() / build_pilots(). Walls
    go on before the carve, pillars after it, pil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
    [battery_shim.stl, cover.stl]
2026-08-20 Correct three stale USB-C comments left from the 1.5x layout
    UC_REAR_Z is 41.0, not 33.0. The mounting-face note described a rejected x=-13
    placement that no longer exists. And the port-channel relief figure was 9.04 mm from a
    first measurement that read UC_PORT_W/H as plan width and height rather than mouth width
    and thickness -- verify.py measures 17.53 on the correct axes. Numbers in code were
    already right; only the prose was wrong.
    Claude-Session: https://claude.ai/code/session_017cy2x8k4PpiL7Z4hingK6P
2026-08-20 The "USB-C breakout" was never the part: cradle the DWEII module instead
    amazon.com/dp/B09YD5C9QC is a DWEII Type-C 5V 2A boost + charge + protect module -- the
    part README §7 already specified as PWR_*, and the part whose own dimension drawing has
    been sitting in this directory as dweii_spec.jpg (Amazon image 61U6muDgZEL) since the
    layout was set. It is not a USB-C breakout.
    mask_params carried a UC_* block for a SparkFun-pattern "USB C Breakout" v10 -- 21.4 x
    14.5 x 4.75, two M3 holes 16.85 apart -- copied wholesale from
    ../sonos-nest/hardware/jukebox-7, where that board really is used. Nothing had ever
    built it, which was the right outcome for the wrong reason; when it finally was bui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
    [cover.stl]
2026-08-20 The cam board is 38 mm wide with a card in it: re-cut the bay around the SD
    PCB_W = 30.4 is the BARE board. With a microSD seated, the slot region juts 7.6 mm past
    one long edge, and nothing in this project knew -- the bay, the posts and the cradle were
    all laid out around a board that is 7.6 mm narrower than the one being fitted.
    MEASURED off the board's own 32 x 24 mm hole pattern in an assembly photo (2026-08-20):
    the card occupies z 51.7..66.0 and stands 6.9 mm proud, reaching x = -22.80. 7.6 is
    carried instead of 6.9, being what the stated 38 mm overall implies, and SD_MARGIN adds
    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
    [cover.stl]
2026-08-20 Swap the SD and the module to their real walls, and fasten the module instead of trapping it
    TWO CORRECTIONS, both from the assembly photo and from what the board actually needs.
    THE SD CARD IS ON THE OTHER WALL. SD_SIDE was read off a verbal description whose
    front/back mirror went the wrong way; the photo is the authority and says the opposite.
    The bay opens toward image-left where the camera seat is, so image-left is the mask's +z
    -- rotate it upright and the card lands at +x, not -x. SD_SIDE = +1 now, PWR_SIDE
    derives from it as before, and the board-zone posts mirror with them:
    (+21,36), (+21,45.5), (-21,59), plus the unchanged waist pair. Everything downstream of
    SD_SIDE follows au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
    [cover.stl, power_clamp.stl]
2026-08-20 The module's pocket was floored over: cut it from the mask, not just from its boss
    Reported as "I don't see screwholes or posts for the usb-breakout, I don't see a hole to
    feed the usb-cable through". Both features were in the file -- but one of them was
    blocked, and a section through the pocket shows why.
    THE POCKET STARTS 1 mm BELOW THE BAY'S FLOOR LEVEL IN Z. That 1 mm is what forms the
    shelf the module rests on. The bay carve stops at BAY_Z0_UP, so those bottom 1 mm sit in
    the bay's LOWER WALL -- and the pocket was only ever differenced out of its own boss in
    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
2026-08-20 Record the cell-polarity trap: a reversed battery reads as a full one
    Found during assembly. The DWEII module's four LEDs are a 25%-per-segment fuel gauge, and
    with the battery pair connected backwards it reads its own open-circuit charger output and
    lights all four -- indistinguishable from a genuinely full cell. The gauge cannot be used
    to confirm the wiring, which is worth writing down because it is the reading you naturally
    reach for.
    Two things catch it for free: a new pouch ships at storage charge (~3.7-3.8 V, one or two
    segments), so four segments on a cell nobody has charged is the wiring; and polarity gets
    metered at the cell's leads rather than taken from wire colour.
    README §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
2026-08-20 Record the DWEII pad map, read off the silkscreen
    The product photo is legible once cropped and upscaled, so the pads are no longer a
    guess: K (switch) on the top edge, the battery +/- pair beside it, the 5V+/5V- output
    pair on the left edge, IC HOTCHIP PB005 3A, four gauge LEDs at the lower right.
    Also recorded, because it is the answer to "how do I turn the LEDs off" and it is not the
    obvious one: the button gates the OUTPUT and the gauge together, and the gauge lights
    during charging regardless of it. Killing the LEDs alone means desoldering them. The
    bay is not lit by them in any case -- components face the wall, so they sit 0.5 mm off
    solid plastic, and the eye plugs blank the only s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
2026-08-20 The boost auto-starts: no button, no cover change
    Tested on the bench. The module wakes on load current, so K stays unwired, nothing has
    to come out through the cover, and the mask powers up on its own after a cycle. That was
    the last open question capable of forcing a cover redesign.
    Recorded with its corollary, which is the part that could still bite: a module that wakes
    on load current sleeps on the absence of it, somewhere around 50-70 mA. Streaming MJPEG
    is far above that, but firmware that ever deep-sleeps the S3 would drop under the cutoff
    and the module would need a button press to come back -- from inside a sealed mask.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
2026-08-21 Confirm the cam board pinout, and say which of its two 5V pads to use
    Photographed on the board being fitted. The sequence recorded from the 2026-08-18 board
    is right -- 48, 1, GND, 5V with the square pad marking pin 1 -- but it is a COLUMN down
    the back left edge, not a row read left to right. Corrected.
    What was not recorded is that there are TWO 5V pads. Besides the edge column there is a
    middle row of four flat SMD pads, GND 5V 47 48, on the same rail; metering 5 V there is
    correct and it is the easier one to reach, which is exactly why it needs a note.
    Use the EDGE pair. On the edge, 5V sits at the end of the column with GND as its only
    live neighbour, so a solder bridge is a shor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
2026-08-21 Remove the "pin 1" ambiguity that nearly cost an S3
    This file said "the square pad is 5V, pin 1", one sentence above a warning that the pad
    marked 1 is GPIO1. Those are two different pads and the sentence collided the ideas: a
    square outline is the PCB convention for a connector first pin and is about the pad SHAPE,
    while the pad silkscreened 1 is GPIO1 and is about the LABEL, three down from the corner.
    Asked which pad to use, the reasonable reading of that sentence was the GPIO -- 5 V into a
    3.3 V signal pin.
    The phrase "pin 1" is gone. The pinout is now counted from the corner mounting hole, with
    the square-versus-round shape as the test: 1st pad square = 5V, 2nd = GND, 3rd = GPIO1 and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
2026-08-21 Exclude the donor model: it is not ours to redistribute
    The mask this project converts is Sri Lankan Mask (Gini Raksha) by Tbridge3D, under the
    Standard Digital File License -- print it yourself, do not re-upload. This repository is
    going public, so the donor 3MF leaves it, along with mask_cam.3mf (which carries the
    donor geometry unchanged) and the five product photographs that came out of that archive.
    The analysis renders stay: face_map, cavity, back_analysis and the previews are our own
    measurements of the surface, not the designer.
    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
2026-08-21 Make the repo resumable: CLAUDE.md, a state section, and the CAD skill
    So a session can be started in a fresh clone and pick up where this one stopped.
    CLAUDE.md carries what does not belong in the design document: that nothing builds without
    the donor, how to invoke the venv one directory up, how long each step takes (verify.py is
    eight minutes -- background it), and the measurement traps that cost real time here.
    mesh.contains() gets OOM-killed on a 1M-face mesh past a few thousand points; thousands of
    single-ray calls segfault; a ray cast exactly along a designed face grazes it and returns
    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
2026-08-21 Say why the sampled grids are missing, instead of raising FileNotFoundError
    A fresh clone cannot import mask_params: it derives every floor and seat from pod.npz at
    import time, and the grids are gitignored. The bare FileNotFoundError that produced said
    nothing about the donor, which is the actual cause.
    measure.py now explains it and gives the fix -- supply your own copy of the donor and run
    build_all.py --force.
    And it records why the grids can never be checked in, because "just commit pod.npz" is the
    obvious way to make a clone self-contained and it is the wrong one. pod.npz carries YF, a
    0.5 mm height map of the donor visible face across the whole silhouette -- the relief, the
    fangs,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
2026-08-21 Give the mask firmware: stream, record, and a way in when WiFi is down
    The CAD side has been finished for a while; this is the software half. It
    follows the same rule: verify against the hardware, not the datasheet.
    Two PlatformIO environments. `selftest` asks the board four questions and
    prints the answers in twenty seconds -- PSRAM, camera, a plausible frame, a
    writable card -- and exists so that a fault three layers into a streaming
    server can be told apart from a fault in the board. `mask-cam` is the real
    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
2026-08-21 Make it record on its own, and keep a rolling window on the card
    Always-on, ring-buffered: the board arms itself as soon as the card mounts
    and deletes the oldest clip when space runs low, so it holds roughly the last
    thirty hours and never needs a button pressed. A power cut can no longer
    leave it streaming happily and recording nothing.
    The capture pump now starts BEFORE the network. Arming early bought nothing
    while the pump came up after wifi_connect(), because no frame exists until
    the pump runs -- so the first twenty seconds after power, exactly the moment
    recording on boot is meant to catch, were being thrown away. Nothing in the
    capture or recording path needs an IP address.
    Deleti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
    [config.h, main.cpp, recorder.cpp]
2026-08-21 Add a bench environment, and measure the two numbers the design hinged on
    Motion detection was about to be designed off published figures for other
    resolutions on other chips. Two measurements on this board instead, and both
    changed the answer.
    The JPEG decode is CHEAPER than the estimate and shaped differently. SVGA at
    JPG_SCALE_8X is 39.4 ms -- against a 50-120 ms guess triangulated from three
    published sources -- and it is deterministic to a tenth of a millisecond over
    eight frames. More useful is the shape: 1/4, 1/2 and 1/1 all cost about
    310-340 ms, because only 1/8 skips the IDCT. It is a cliff, not a slope, so
    there is exactly one usable scale for detection and it happens to be the o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
    [main.cpp]
2026-08-21 Detect motion, and annotate the footage rather than gating it
    Phase 1 deliberately does not control recording. The ring keeps everything it
    kept before; the detector only writes events beside it, into /motion.log, each
    naming the clip AND the offset into it so an event points at footage rather
    than at a wall-clock time. A wrong threshold therefore costs a wrong label and
    never footage -- which is the difference that matters when the thing being
    tuned ends up behind a screwed-down cover. It also produces the false-positive
    record needed before gating anything on it.
    Built on the two measurements from the bench rather than on the literature.
    Decode is JPG_SCALE_8X and nothing else: 39 ms for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
    [config.h, main.cpp, recorder.cpp]
2026-08-21 Make the mask updatable over the air, because soon it will be sealed
    Once the cover goes on there is no wired path to this chip. The USB-C that
    reaches the outside goes to the POWER module's charging socket; the ESP32's
    own USB is on the cam board, inside the bay, behind ten screws. The USB
    console added earlier as "the way in when WiFi is down" stops being reachable
    the moment the mask is assembled, and without this the thing would be a
    write-once device -- with an untuned motion detector that explicitly needs
    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
2026-08-21 Turn the picture the right way up, and remember which way that was
    The camera module sits in the mask's pocket lens-forward, which puts the
    sensor in upside down: the image came back inverted, scene and all. This was
    listed as open -- "which way is up, not checked against how the mask hangs" --
    and it is now answered by looking at one.
    Both axes, not one. A 180 degree rotation needs vflip AND hmirror; setting
    only vflip turns the picture the right way up and leaves it MIRRORED, which is
    the sort of thing nobody notices until they try to read something in the
    footage. With no text in frame the way to tell them apart is to watch what
    crosses the frame: under a real rotation something on the l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
    [capture.cpp, config.h]
